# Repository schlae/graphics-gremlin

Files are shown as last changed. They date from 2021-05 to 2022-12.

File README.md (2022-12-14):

# The Graphics Gremlin - a Retro ISA Video Card

The Graphics Gremlin is an FPGA-based ISA video card specifically designed to emulate certain old video standards. This initial release emulates the original IBM PC monochrome graphics adapter (MDA) as well as the original IBM color graphics adapter (CGA). Since the logic is defined by the bitstream loaded into the FPGA, new emulations may be available in the future to support other video standards.

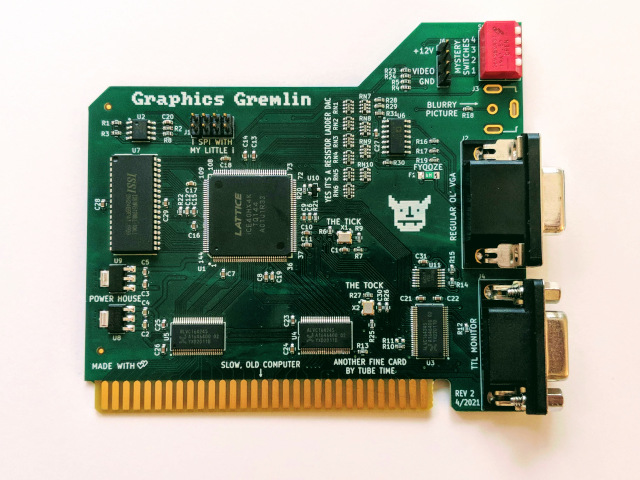
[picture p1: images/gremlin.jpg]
Graphics Gremlin PCB photo


But why emulate an old video card when they are still fairly easy to find online? Cards aren't hard to find, but monitors that can sync to the unusual frequencies used by MDA (18KHz) and CGA (15KHz) are much harder to find, and these frequencies are rarely supported by modern LCD monitors or video capture hardware.

For both MDA and CGA, the Graphics Gremlin has a VGA port that can deliver video running at standard (31KHz) frequencies that are well supported by LCD monitors, VGA-to-HDMI converters, and USB capture devices.

Here are the design files. The BOM includes Mouser Electronics parts numbers for everything except for the 0.1" headers which are typically cut to length anyway.

[Schematic](https://github.com/schlae/graphics-gremlin/blob/main/isavideo.pdf)

[Bill of Materials](https://github.com/schlae/graphics-gremlin/blob/main/isavideo.csv)

[Fab Files](https://github.com/schlae/graphics-gremlin/blob/main/fab/isavideo_rev2.zip)

## Fabrication and Assembly Notes

The circuit board is a 2-layer board, 4.19 x 3.74 inches (106 x 95mm). No special edge connector bevel is required, but you may want to specify at least ENIG plating. If you are rich then you could spend the extra money and get hard gold plated edge fingers. Order the boards with a fancy soldermask color so you can show off, or stick with a plain green to blend in.

You probably shouldn't attempt this project if you've never soldered surface mount components before. It'll lead to a lot of frustration and potentially damaged boards and parts.

There are two main methods you can use to assemble the board: reflow and hand soldering. Using the reflow method means that you'll need to order the solder stencil for the top side (there are no parts on the bottom of the board), and be sure to have fresh solder paste and some sort of vacuum pick-and-place tool. This method can be very quick but does require some skill and practice. 

Hand soldering is good when you only want to assemble a single board. This board has no BGA or leadless components which makes hand soldering possible. Some components have a very fine lead pitch (0.5mm) so only attempt this if you are comfortable with your soldering skills.

No matter which method you use, I recommend inspecting every solder joint very carefully under a microscope to make sure there are no solder bridges. If there are, clean them out with some solder braid.

Be careful not to mix up the two voltage regulators: they provide *different* voltages!

R11 should not be stuffed. By default this means that the 14.318MHz clock is generated on board. If you *move* R25 to R11, then the 14.318MHz clock comes from the ISA bus. The motherboard's 14.318MHz oscillator isn't always accurate enough for CGA color composite video.

Header J6 is optional. If you want to install it, remove pin 2 for keying.

Before plugging the card into a PC, it is wise to use a multimeter to verify that there are no short circuits between the +5V line (ISA bus pin B3) and ground or between the +12V line (ISA bus pin B9) and ground.

The card bracket may be fabricated from a plain, blank bracket such as a Keystone Electronics 9200. The dimensions are included in the KiCad file on the Dwgs.User layer. The best way to make holes in the bracket is by using a hand-operated sheet metal punch. A chassis nibbler is useful for making the DE-9 openings and the opening for the DIP switch bank.

You can also try 3D printing the bracket using the file below. There is a small line printed near the top which marks where you have to bend the bracket after you finish printing it. Use a hair dryer or a heat gun (on low) to soften it, and then bend it over a straightedge or ruler. For a slightly better finish on the outside of the bracket, flip it over in your slicer software so that the outside surface faces the bed of the printer.

[ISA bracket STL file](https://github.com/schlae/graphics-gremlin/blob/main/isabracket.stl)

## The FPGA
[A separate document discusses the Verilog code.](https://github.com/schlae/graphics-gremlin/blob/main/verilog/README.md)

Programming the FPGA is fairly easy and can be done with an FTDI FT2232H Mini Module [datasheet here](https://www.ftdichip.com/Support/Documents/DataSheets/Modules/DS_FT2232H_Mini_Module.pdf).

Wiring for the FT2232H mini module is as follows:

| Point 1 | Point 2 | Description |
| --- | --- | --- |
| CN2 pin 1  | CN2 pin 11 | V3V3 to VIO strap |
| CN3 pin 1  | CN3 pin 3 | VBUS to VCC strap |
| CN2 pin 3  | CN3 pin 12 | V3V3 to VIO strap (2) |
| CN2 pin 14  | SPI cable pin 1 | CS |
| CN2 pin 16  | SPI cable pin 2 | CDONE |
| CN2 pin 7 | SPI cable pin 3 | SCK (serial clock) |
| CN2 pin 15  | SPI cable pin 4 | CRESET |
| CN2 pin 9 | SPI cable pin 5 | CIPO (controller in, peripheral out) |
| CN2 pin 2 | SPI cable pin 6 | GND |
| CN2 pin 10  | SPI cable pin 7 | COPI (controller out, peripheral in) |
| n/a | SPI cable pin 8 | not used |

To program the FPGA, power needs to be applied. The simplest way to do this is to drop it in a nearby PC and turn it on. With the cable plugged in to a USB port, you can use the [Project IceStorm](http://www.clifford.at/icestorm/) tool "iceprog" to program the SPI flash memory.

`iceprog -p isavideo.binm`

Once the SPI flash has been programmed, iceprog toggles the reset line so that the FPGA loads the new bitstream. At this point it will be active on the ISA bus, but the PC's BIOS doesn't know about it. Reboot the computer and it should find it.

Note that leaving the programming cable plugged in can sometimes cause issues with the FPGA being held in reset when the PC powers up. In that case, simply unplug the cable and reboot the PC.

### Windows Instructions
Thanks to [midicdj1000](https://github.com/midicdj1000), here are some instructions for programming the FPGA using Windows.

1. Download and extract the Windows build of the [OSS CAD Suite](https://github.com/YosysHQ/oss-cad-suite-build/releases).
2. Connect the FT2232H mini module according to the directions in the previous section.
3. Install the [FTDI driver](https://ftdichip.com/drivers/).
4. Change the driver to libusbK using these [instructions](https://learn.adafruit.com/adafruit-ft232h-breakout/windows-setup).
5. From the command line in the Bin folder of the OSS-CAD-Suite folder, run `iceprog -p isavideo.binm`. (Be sure to include the appropriate path to the isavideo.binm file, or simply copy the file into the Bin folder.)

## The Red Switch Bank

The red switch bank on the top right of the card controls two things: the bitstream selected by the FPGA when it powers up and specific settings for the selected bitstream.

The bitstream is selected using switches 3 and 4:

| 3 | 4 | Description  | Default |
| --- | --- | --- | --- |
| open | open | Bitstream 0  | MDA (VGA compatible signal) |
| open | closed | Bitstream 1  | MDA (MDA monitors only) |
| closed | open | Bitstream 2  | CGA (both VGA and CGA compatible signals) |
| closed | closed | Bitstream 3  | Not used |

For example, if you want to use MDA with a VGA monitor, set switches 3 and 4
to the open (up) position. (CGA has support for both VGA and CGA monitors built in since it implements a line doubler.)

The remaining two switches have a function that is bitstream-dependent.

| Switch | MDA (VGA comp.) | MDA | CGA |
| --- | --- | --- | --- |
| 1 | Not used | Not used | closed=composite mode. open=VGA mode |
| 2 | Not used | Not used | closed=thin font. open=normal font |

## Connectors

The Graphics Gremlin provides both a 9-pin RGBI connector and a 15-pin VGA connector. The 9-pin connector is designed for use with digital monitors such as the IBM 5151, 5153, or a variety of older multisync monitors.

The RCA jack is used for CGA composite video when that bitstream is selected (see the previous section). Note that the signal for the RCA jack is also used as the green channel for the VGA connector so they cannot both be used at the same time.

Connector J6 is for compatibility with IBM CGA cards which provide the composite signal for RF modulators. This connector is really only useful if you want to use the card with an IBM 5155 Portable PC (the internal monitor has a cable that plugs into this connector).

## Troubleshooting

This is a complex card with many fine-pitch components, so most likely any issues you run into will be caused by a solder bridge or broken connection. Go back and check each solder joint using a microscope. Make sure you didn't install any chips or the clock oscillators the wrong way around.

A few things to confirm for basic operation include:

1. Are the 3.3V and 1.2V regulators putting out those voltages?
2. Are the two clock oscillators generating 10MHz and 14.318MHz?
3. Can the SPI flash get programmed by the FTDI board *and verified?*

Unlike the namesake video cards of old, the FPGA comes up with the internal card registers fully programmed and the card should generate video even if the ISA bus interface isn't working at all. A simple check involves configuring the switch bank for CGA and confirming that it produces a video signal. You can even flip to composite mode to make sure that works as well.

Checking these first can help you narrow down the source of the problem.

To confirm proper operation on the ISA bus, it's helpful to set up a PC with a VGA card (or CGA card) and the Graphics Gremlin configured for MDA. These can coexist on the same PC.

Boot up the PC and run the DOS DEBUG program. Then see if you can access the CRTC registers. Unlike the original MDA card, these can be read back. Note: if you use the VGA compatible MDA mode, then these registers cannot be written to.

```
o 3b4 0
i 3b5
```

This should return a number that is not 0 or FF. (The exact number depends on which MDA bitstream you are using).

If that works, then check to see if you can read and write the MDA video memory area:

`e b000:0000 55 aa 55 aa`...

and to check what you just wrote

`d b000:0000`

This will exercise the connections to the SRAM.

Other strange things that can happen:
* If the PC just beeps out an error code during startup, check for motherboard jumpers or switches that have to be set. You might also try a dual video card setup with a VGA card.
* If the PC never boots at all, it could be that the IO\_READY pin (A10) on the ISA bus is stuck low. Also check for any short circuits on the address, data, or control lines.
* If the PC power supply refuses to start or if there is smoke, then you probably have a short circuit on the +5V or +12V line on the card. Check for things like solder paste smeared underneath capacitors or traces shorted to the ground plane.

In general, use a logical process of elimination to find where the fault (or faults!) lurks.

## Emulation Accuracy

The logic for both the MDA and CGA cards is as close as I could get it to match the schematics available in the technical reference manuals, with two exceptions. The VRAM interface is specific to the 8-bit SRAM chip that I am using instead of the 16-bit SRAM on the original MDA or the 16-bit DRAM used on the CGA, so it had to be quite different from the originals. As a result, the sequencer state machine had to be designed from scratch. There are some other minor differences mostly to support the nonstandard VGA-compatible signal outputs.

Accuracy is a work in progress. Certain demos, like 8088MPH, that require cycle-accurate operation on a 4.77MHz PC, don't work 100% correctly. The causes of this aren't yet fully understood.

## Future Plans

Although the card supports just MDA and CGA, I'd like to support other video standards in the future. EGA and even VGA would be nice, but there are two huge challenges associated with that: they use custom gate array chips and they also use a 32-bit memory bus. This means I would need to quadruple the pixel clock to produce four 8-bit fetches from the SRAM. Due to this bus bandwidth limitation, Super VGAs are totally off the table.

Other people have requested support for Hercules, Tandy, and PCjr graphics, which I might get around to implementing someday.

There are also some neat non-graphics uses for the card. With some clever programming, the card could be turned into a memory card to extend the RAM in some of the older IBM PC and XT machines (XMS RAM). It could also emulate an expanded memory card for machines that can't run EMM386. BIOS extension ROMs stored in the NOR flash chip could also be mapped to ROM areas in the PC memory map, which might also be useful.

The card could act as a fancy POST card, perhaps even with a mini bus analyzer built in (using a connected VGA monitor).

It's even theoretically possible to implement a sound card using the composite video jack (and 7-bit resistor DAC) as the sound output.

## License
This work is licensed under a Creative Commons Attribution-ShareAlike 4.0
International License. See [https://creativecommons.org/licenses/by-sa/4.0/](https://creativecommons.org/licenses/by-sa/4.0/).

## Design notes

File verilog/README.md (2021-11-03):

# The Graphics Gremlin - FPGA code

(Click here for the [main README](https://github.com/schlae/graphics-gremlin/blob/main/README.md))

The FPGA code is divided into two major sets of files, those for CGA graphics and those for MDA graphics. At some point I'll tidy up and make a nice organized directory tree, but for now they're all in the same place.

* mda\_top.v: The top level file instantiating the MDA graphics logic
* mda70\_top.v: An alternative top level file for VGA compatible MDA graphics
* mda.v: Implements MDA ISA interface, IO registers and instantiates the CRTC, SRAM interface, sequencer, and pixel engine
* crtc6845.v: This is my mostly-accurate recreation of the old Motorola 6845 CRT controller chip. It generates all the sync timings as well as the character and row addresses. There are probably slight differences between it and the real thing.
* mda\_sequencer.v: Controls timing across the entire card, deciding when to fetch SRAM data, look up character bits from the character ROM, and allow ISA bus access to the SRAM
* mda\_vram.v: Implements the state machine to arbitrate ISA bus and pixel engine access to the video ram (external SRAM)
* mda\_pixel.v: This is the pixel engine. It takes data coming from the SRAM, looks up the pixels in the character ROM, and shifts the data out one pixel at a time. 
* mda\_attrib.v: The attribute generator applies video attributes to the raw pixel data, including brightness, underline, inverse video, blinking. It also applies the blinking cursor.
* mda\_vgaport.v: This module turns the digital MDA video signals into numbers to drive the resistor ladder DAC connected to the VGA port. If you (gasp) dislike amber monochrome monitors, then you can hack this code to make it green or white.

CGA graphics logic is similar to MDA and shares the same crtc6845.v logic, but the cards are different enough that I couldn't share more.
* cga\_top.v: Instantiates top level CGA logic.
* cga.v: Implements the ISA bus interface, CGA control registers, wait state generator, and most of the other CGA modules
* cga\_sequencer.v: Generates most of the timing signals used on the card, including memory fetches and pixel engine timing.
* cga\_vram.v: Implements a very basic address MUX for the SRAM interface. This actually causes too much CGA snow, and should be improved using the MDA VRAM interface as a model.
* cga\_pixel.v: The CGA pixel engine takes data from the SRAM, does a character lookup (text mode only), and shifts the data out 1 or 2 bits at a time, depending on the video mode.
* cga\_attrib.v: The attribute generator applies video attributes to the raw pixels data, including color, brightness, and blinking.
* cga\_composite.v: Contains the flip flops used to generate NTSC composite color as well as new sync pulses. The output is a 7-bit signal passed off to the green DAC channel for the RCA jack on the card.
* cga\_scandoubler.v: A very basic scan doubler to convert 15.7KHz CGA video to 31.4KHz VGA video. To save memory, this is done using 4-bit digital RGBI signals.
* cga\_vgaport.v: This module takes RGBI digital video from the scan doubler and turns it into numbers that drive the resistor ladder DAC connected to the VGA port. It produces CGA brown instead of dark yellow.

Other miscellaneous files include:
* cga.hex and mda.hex: character ROM
* gremlin.pcf: The pin constraints file that determines what signals are tied to what pins on the FPGA
* isavideo\_t.v: A sloppy test bench that I used to validate and troubleshoot the rest of the logic.
* is61c5128\_t.v: A behavorial Verilog model of the SRAM chip.
* is61\_tester.v: A test bench I used to verify the SRAM chip behavioral model.

## Building

To build the project, you will need to install the tools from [Project IceStorm](http://www.clifford.at/icestorm/) (full instructions are available at that link). The Graphics Gremlin uses NextPNR, so make sure you install that.

Alternatively, you can install the [OSS Cad Suite](https://github.com/YosysHQ/oss-cad-suite-build) which is prebuilt and runs on a variety of platforms.

Once the tools are installed, just navigate to the Graphics Gremlin Verilog directory and run
```
mkdir build
make
```
If you have the FTDI programming cable hooked up to the card, you can also type `make prog`. As a convenience, `make reset` will not program the FPGA but will toggle its reset line which is useful if you change the red switch bank and don't want to cycle power on the host PC.

If the `make prog` command can't find the FTDI programming cable, make sure you have the udev rules set up.

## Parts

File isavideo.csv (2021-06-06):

Item | Qty | Reference(s) | Value | Mouser
1 | 23 | C1, C7, C8, C9, C10, C11, C13, C14, C15, C16, C17, C20, C21, C22, C23, C24, C25, C26, C27, C28, C29, C30, C31 | 1u | 810-CGA3E1X7R1C105AC
2 | 8 | C2, C3, C4, C5, C6, C12, C18, C19 | 4.7u | 187-CL10A475KP8NNNC
3 | 1 | F1 | 1A | 530-0ZCJ0050FF2G
4 | 1 | J1 | PROG
5 | 1 | J2 | DE15 | 156-3315-E
6 | 1 | J3 | NTSC | 161-0360-E
7 | 1 | J4 | DE9 | 152-3409
8 | 1 | J6 | RFMOD
9 | 13 | R1, R2, R3, R4, R5, R8, R9, R14, R15, R20, R23, R24, R27 | 10K | 603-RC0603FR-0710KL
10 | 5 | R6, R7, R10, R25, R26 | 10 | 603-RC0603FR-0710RL
11 | 1 | R11 | DNI | DNI
12 | 3 | R12, R21, R22 | 100 | 603-RC0603FR-07100RL
13 | 1 | R13 | 1K | 603-RC0603FR-071KL
14 | 5 | R16, R17, R18, R19, R31 | 75 | 603-RC0603FR-0775RL
15 | 3 | R28, R29, R30 | 237 | 603-RC0603FR-07237RL
16 | 6 | RN1, RN2, RN3, RN4, RN5, RN6 | 604 | 652-CAY16-6040F4LF
17 | 4 | RN7, RN8, RN9, RN10 | 300 | 652-CAY16-3000F4LF
18 | 1 | SW1 | SW_DIP_x04 | 706-76PSB04ST
19 | 1 | U1 | ICE40HX4K-TQ144 | 842-ICE40HX4K-TQ144
20 | 1 | U2 | SST26VF080A-104I/SN | 579-26VF080A-104I/SN
21 | 3 | U3, U4, U5 | 74ALVC164245 | 771-74ALVC164245
22 | 1 | U6 | ADA4891-3 | 584-ADA4891-3ARZ
23 | 1 | U7 | IS61WV5128BLL-10KLI | 870-61WV5128B10KLI
24 | 1 | U8 | AP2114HA-3.3 | 621-AP2114HA-3.3TRG1
25 | 1 | U9 | AP2114HA-1.2 | 621-AP2114HA-1.2TRG1
26 | 1 | U10 | APX803S00-29SA-7 | 621-APX803S00-29SA-7
27 | 1 | U11 | 74HCT125 | 771-74HCT125PW-T
28 | 1 | X1 | 10MHz | 520-ECS-2333-100-BNT
29 | 1 | X2 | 14.318MHz | 815-ASE-14.318MLCT

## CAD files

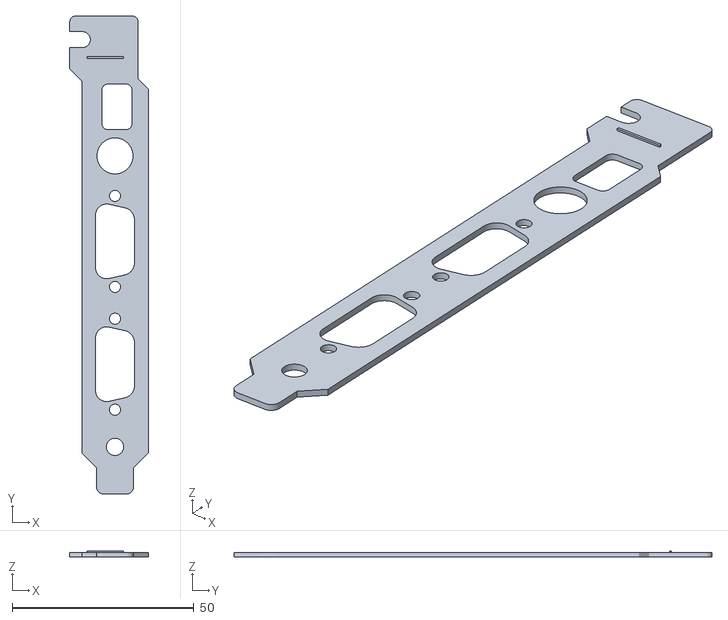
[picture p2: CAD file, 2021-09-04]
isabracket.stl
21.6 x 131.4 x 1.67

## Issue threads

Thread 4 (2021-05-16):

Question about the specified board size

ecm-pushbx, 2021-05-16:
I don't really go here but I found the following part of the readme file curious:

> The circuit board is a 2-layer board, 4.19 x 4.2 inches (106 x 95mm).

1. The shorter and longer sides seem to be swapped between the inches and millimetres specifications.
2. I don't see how the values are accurate matches. Perhaps the "4.2 inches" should be "4.02 inches"? That still wouldn't match exactly though.

schlae, 2021-05-16:
The height should be 3.74in, or 95mm. I've corrected it in the board file and the readme.

Closed 2021-05-16.

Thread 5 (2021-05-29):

MDA 70Hz RAM issues

schlae, 2021-05-29:
MDA (70Hz VGA compatible) on some boards has issues with the attribute byte getting corrupted by the previously-read character byte. This shows up as spurious underlines, inverse video, etc on the screen. Likely this is a marginal timing issue as it works fine on some boards but not others.

spark2k06, 2021-10-30:
I have investigated and discovered something about this issue, and that is that the final timing resulting from the build plays an important role. The most curious thing is that this final timing can be manipulated by inserting or extracting modules not required by the project.

So, for example, a build only with the modules required by the project:

`yosys -p 'synth_ice40 -top mda70_top -json build/mda70_top.json' mda70_top.v mda.v crtc6845.v mda_vgaport.v mda_vram.v mda_attrib.v mda_sequencer.v mda_pixel.v -E mda70_top.d
`

`Total path delay: 12.21 ns (81.89 MHz)`

This timing seems that it would not be compatible with any board, causing artifacts.

Ahora, con la build utilizada por el Makefile, basada en los últimos cambios que afectarían sólo al proyecto de CGA:

`yosys -p 'synth_ice40 -top mda70_top -json build/mda70_top.json' mda70_top.v mda_top.v mda.v crtc6845.v mda_vgaport.v mda_vram.v mda_attrib.v mda_sequencer.v mda_pixel.v cga_top.v cga.v cga_vgaport.v cga_sequencer.v cga_pixel.v cga_attrib.v cga_vram.v cga_composite.v cga_scandoubler.v -E mda70_top.d `

`Total path delay: 12.66 ns (78.98 MHz)`

This timing is what causes underlines to occur on some boards, and only show some artifacts. However, if we repeat the command but with the old CGA project files, we get the following result:

`Total path delay: 13.12 ns (76.24 MHz)`

Now yes, this timing could be friendlier with all boards, at least it is with mine:

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

And the most curious thing is that adding repeated modules does not always cause a lower timing, sometimes the opposite happens ... in the tests I have done, I have obtained different timings:

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

In conclusion, timings higher than 80 Mhz could affect any board, and the main symptom is artifacts, which would increase as the frequency is higher. On the other hand, there is a point at which, the timings could be stable on any board, 77Mhz and lower.

schlae, 2021-10-30:
Thanks for going through this, it's a good clue about the root cause of the problem, which is probably the bus timing of the SRAM chip. The fetching of the character and attribute byte are in successive cycles, but perhaps there's not enough time allowed for the address to stabilize before the byte gets latched.

spark2k06, 2021-11-06:
With the latest version of yosys (0.11+1) this issue is also corrected, without the need to make changes to the code.

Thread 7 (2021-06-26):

Can I replace with ICE40HX1K-TQ144?

yeokm1, 2021-06-26:
Hi

I'm intending to assemble your board however I realised ICE40HX4K-TQ144 is out of stock everywhere.

Will a ICE40HX1K-TQ144 work instead?

schlae, 2021-06-26:
No, the 1K has fewer I/O pins, and the Gremlin uses nearly every available I/O on the 4K. You'll just have to wait until they get back in stock.

Closed 2021-06-26.

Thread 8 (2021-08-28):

ICE40HX chips might have 5V tolerant I/O

kiwidrew, 2021-08-28:
If you're willing to live a little bit dangerously the second 74ALVC164245 (U5) may not be necessary because [it appears that the HX4K has 5V tolerant I/O pins](https://www.eevblog.com/forum/fpga/ice40-hx-a-5v-tolerant-fpga/) despite what the datasheet claims.

schlae, 2021-11-05:
I hesitate to design it this way--the FPGA won't last as long due to possible electromigration effects.

Closed 2021-11-05.

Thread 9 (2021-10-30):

MDA 70Hz out of sync with the first MSDOS EDIT

spark2k06, 2021-10-30:
I do not know if it is something that only happens to me, but below I show a video where this effect can be observed. First run of MSDos EDIT command, results in VGA out of sync, I go out and back in, and it always works fine now:

https://youtu.be/G0YuSTjFQO0

spark2k06, 2023-01-25:
It could be related to the CRTC registry values, discussed in the next issue:

https://github.com/schlae/graphics-gremlin/issues/15

Closed 2023-01-25.

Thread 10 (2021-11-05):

Latest yosys synthesis results in missing CGA characters

schlae, 2021-11-05:
Using the 3-Nov-2021 build of oss-cad-suite-build results in the CGA text generation code not synthesizing correctly. Instead of a full character, each cell just displays a single column.

avlixa, 2021-11-20:
Hi,
Try changing this in cga_pixel.v

    // This must be a mux. Using a shift register causes very weird
    // issues with the character ROM and Yosys turns it into a bunch
    // of flip-flops instead of a ROM.
    wire [2:0] charpix;
    assign charpix = hres_mode ? (clk_seq[3:1] + 3'd6) : (clk_seq[4:2] + 3'd7);

    always @ (*)
    begin
        if (video_enabled) begin
            // Hi-res vs low-res needs different adjustments
            //case (hres_mode ? (clk_seq[3:1] + 3'd6) : (clk_seq[4:2] + 3'd7))
            case (charpix)

It seems using the sentece directly in the case is generating a signal with more than 3 bits.  I tried it in @spark2k06 ZXUncore version and it works.

schlae, 2021-11-20:
Yes, this makes sense. The original design infers an adder and there's an ambiguity regarding the resulting bit width: looks like the newer versions of Yosys include the carry out which makes the mux 4 bits wide instead of 3. The result doesn't wrap correctly and triggers the default case for most of the clock sequence. I've pushed your recommended fix, thanks for looking at it!

Closed 2021-11-20.

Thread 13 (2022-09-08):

Unavailability of parts

0ddjob, 2022-09-08:
A few parts are currently unavailable from several suppliers with long lead-times from the manufacturer - is there a possibility of alternatives?

U1: iCE40HX4K-TQ144
U10: APX803S00-29SA-7

schlae, 2022-09-08:
U10: A large number of alternatives are available, this is a clone of a MAX803. be sure to check voltage levels and pinouts before substituting.
U1: No alternatives. We just have to wait until it gets back into stock :(

midicdj1000, 2022-12-15:
HI, Any alternatives for the RCA socket ?

Closed 2022-09-08.

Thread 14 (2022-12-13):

I am just looking for more information that is beginner friendly

midicdj1000, 2022-12-13:
HI, I have lots of experience assembling boards, but not so much programming fpga so when it gets to the part that says run iceprog to program and you then spend days following guides and compiling this and messing with linux only too find a windows version the next day  then the ftdi programmer needs to have it's driver forced because iceprog can't find it and it can't be on a certain sub port, you can imagine someone who does not have fpga experience can have one or two problems.

So after a lot of messing about I can talk to the ftdi, but it will not program the fpga so I need to check a lot of things.

This is how to change the driver
https://github.com/YosysHQ/icestorm/issues/141

and the windows build
https://github.com/YosysHQ/oss-cad-suite-build/releases

Once I have everything working I could document and perhaps it will help others.

midicdj1000, 2022-12-13:
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
This is how far I am and clearly have a big problem with the fpga not running or how I connected the programmer ?

midicdj1000, 2022-12-13:
Success.... I missed one of the connections for the ftdi power setup and it's programmed and is working.
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

midicdj1000, 2022-12-13:
This is how I did it.
Download and extract
https://github.com/YosysHQ/oss-cad-suite-build/releases

Connect the ftdi as per the instructions

install the ftdi driver
https://ftdichip.com/drivers/

Follow these instructions to change the driver to libusbK
https://learn.adafruit.com/adafruit-ft232h-breakout/windows-setup

copy isavideo.binm into the Bin folder of the OSS-CAD-Suite install

then you can run
iceprog -p isavideo.binm

I hope this helps windows users

Closed 2022-12-13.

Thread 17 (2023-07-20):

Memory errors in CheckIt, screen corruption in MDA mode

skiselev, 2023-07-20:
The FPGA byte code from November 20, 2021 (the latest) produces memory errors at certain memory addresses in both MDA and CGA modes.
It also results in memory/screen corruption in MDA mode. The location on the screen seem to correspond to these addresses (typically column 64).
The issue is reproducible in several cards built exactly according to the BoM.

Typical error locations:
* CGA: 0xB9000, 0xBA000
* MDA: 0xB0080, 0xB0400, 0xB0800, 0xB0880, 0xB0C80

Different cards might show errors only in some of these locations. Perhaps there is a timing violation that results in memory corruption in for these certain addresses

schlae, 2023-07-20:
Yes, it's a timing issue, I haven't yet been able to track it down.

skiselev, 2023-07-20:
Tried rebuilding with Yosys-0.31+1 (oss-cad-suite-linux-x64-20230719.tgz), and I am getting even more memory corruption.
Seems to be every location 0x20'th location
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

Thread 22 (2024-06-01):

Exact wiring when using UM-FT2232H instead of FTDI FT2232H Mini Module

explit7, 2024-06-01:
I want to use the ELV UM-FT2232H Kit because its much cheaper than the FTDI FT2232H Mini Module.
The wiring is a bit different than that, what you give for FTDI FT2232H Mini Module:
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

I found where to connect the AD0, AD1, AD2, AD4, AD6, AD7 and GND lines,
ELV UM-FT2232H         Graphics Gremlin SPI

- PIN9 (AD4)             ->    PIN1
- PIN11 (AD6)           ->    PIN2
- PIN5 (AD0)             ->    PIN3
- PIN12 (AD7)           ->    PIN4
- PIN7 (AD2)             ->    PIN5
- PIN4 GND)             ->    PIN6
- PIN6 (AD1)             ->    PIN7

but what i dont understand are the:
V3V3 to VIO strap
VBUS to VCC strap
V3V3 to VIO strap (2)

Maybe you can give a short explanation which PINs i need to use for this 3 connections?
Thanks
[https://github.com/mariusgreuel/um-ft2232h?tab=readme-ov-file](url)

Update: I could program graphics gremlin, without this 3 wires, but i don't know, if it can be dangerous for the FPGA

explit7, 2024-06-24:
I will close this issue, as it seems, that the Pins

- V3V3 to VIO strap
- VBUS to VCC strap
- V3V3 to VIO strap (2)

which are missing on ELV UM-FT2232H are not necessary to flash the cardd

Closed 2024-06-24.

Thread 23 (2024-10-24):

Centroid file

cstruter, 2024-10-24:
I just ordered this on pcbway, but you didnt supply a centroid file.
[https://www.pcbway.com/project/shareproject/The_Graphics_Gremlin_a_Retro_ISA_Video_Card_8294bddc.html](url)

cstruter, 2024-10-24:
[PickAndPlace_isavideo_2024-10-24.xlsx](https://github.com/user-attachments/files/17511319/PickAndPlace_isavideo_2024-10-24.xlsx)
Is this good enough?

schlae, 2024-10-24:
Fixed, the CSV coordinate file is now in the fab package, see 9954a99.

Closed 2024-10-24.

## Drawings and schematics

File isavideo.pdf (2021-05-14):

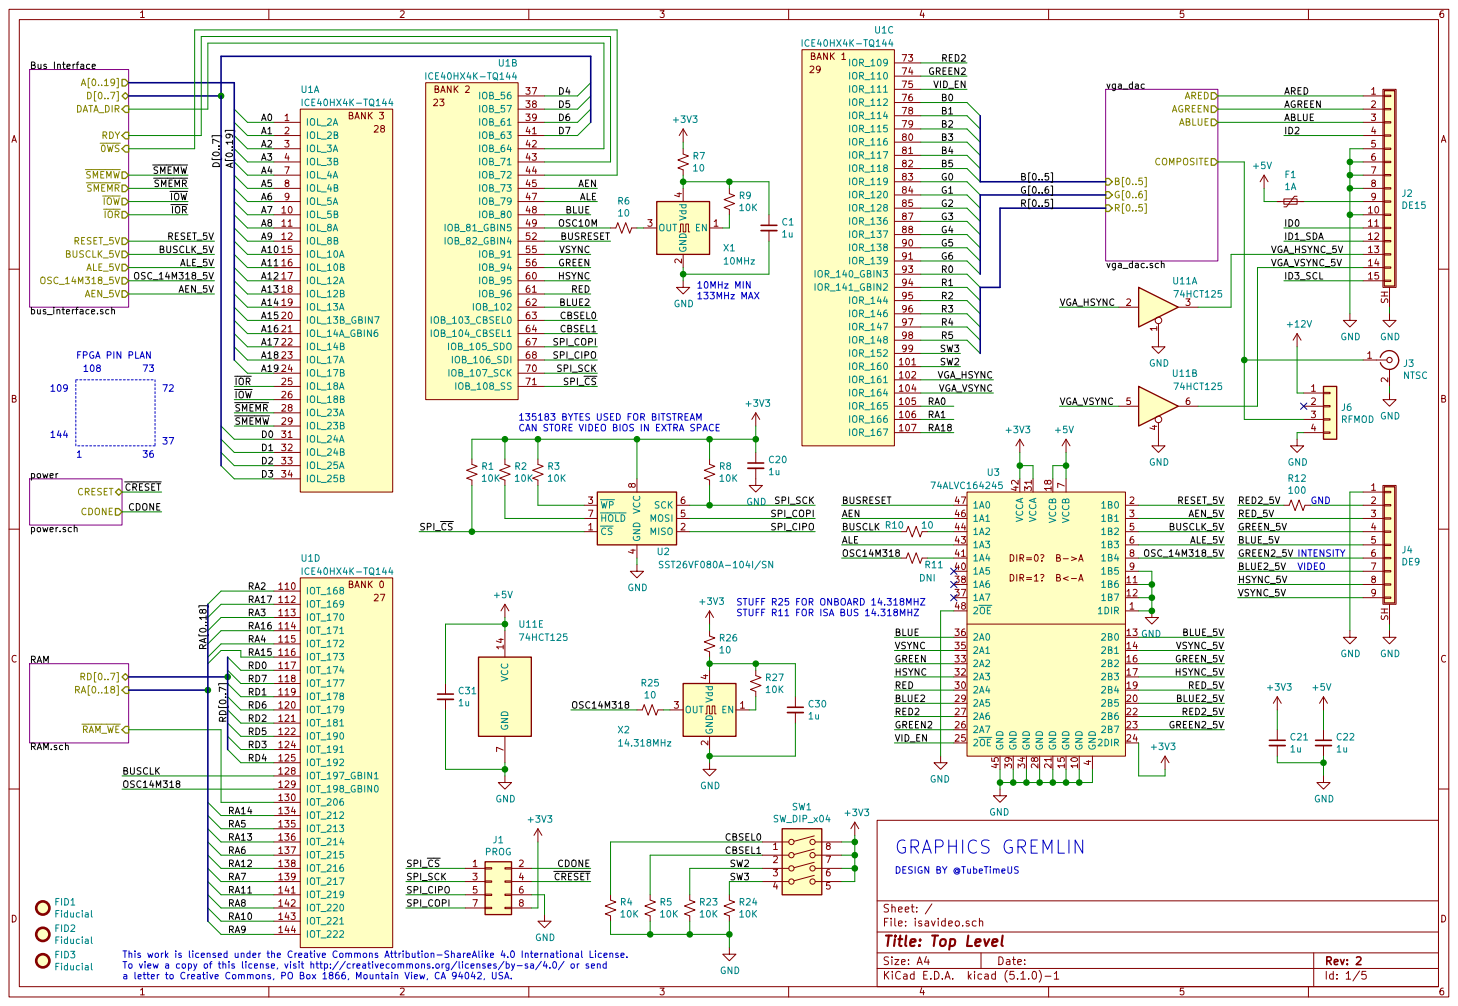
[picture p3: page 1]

AEN
ALE
BLUE
STUFF R25 FOR ONBOARD 14.318MHZ STUFF R11 FOR ISA BUS 14.318MHZ OSC10M

74HCT125 VCC 14 GND
135183 BYTES USED FOR BITSTREAM

4 MOSI 5 SCK 6 HOLD 7 VCC

IOT_198_GBIN0 129
IOT_206 130

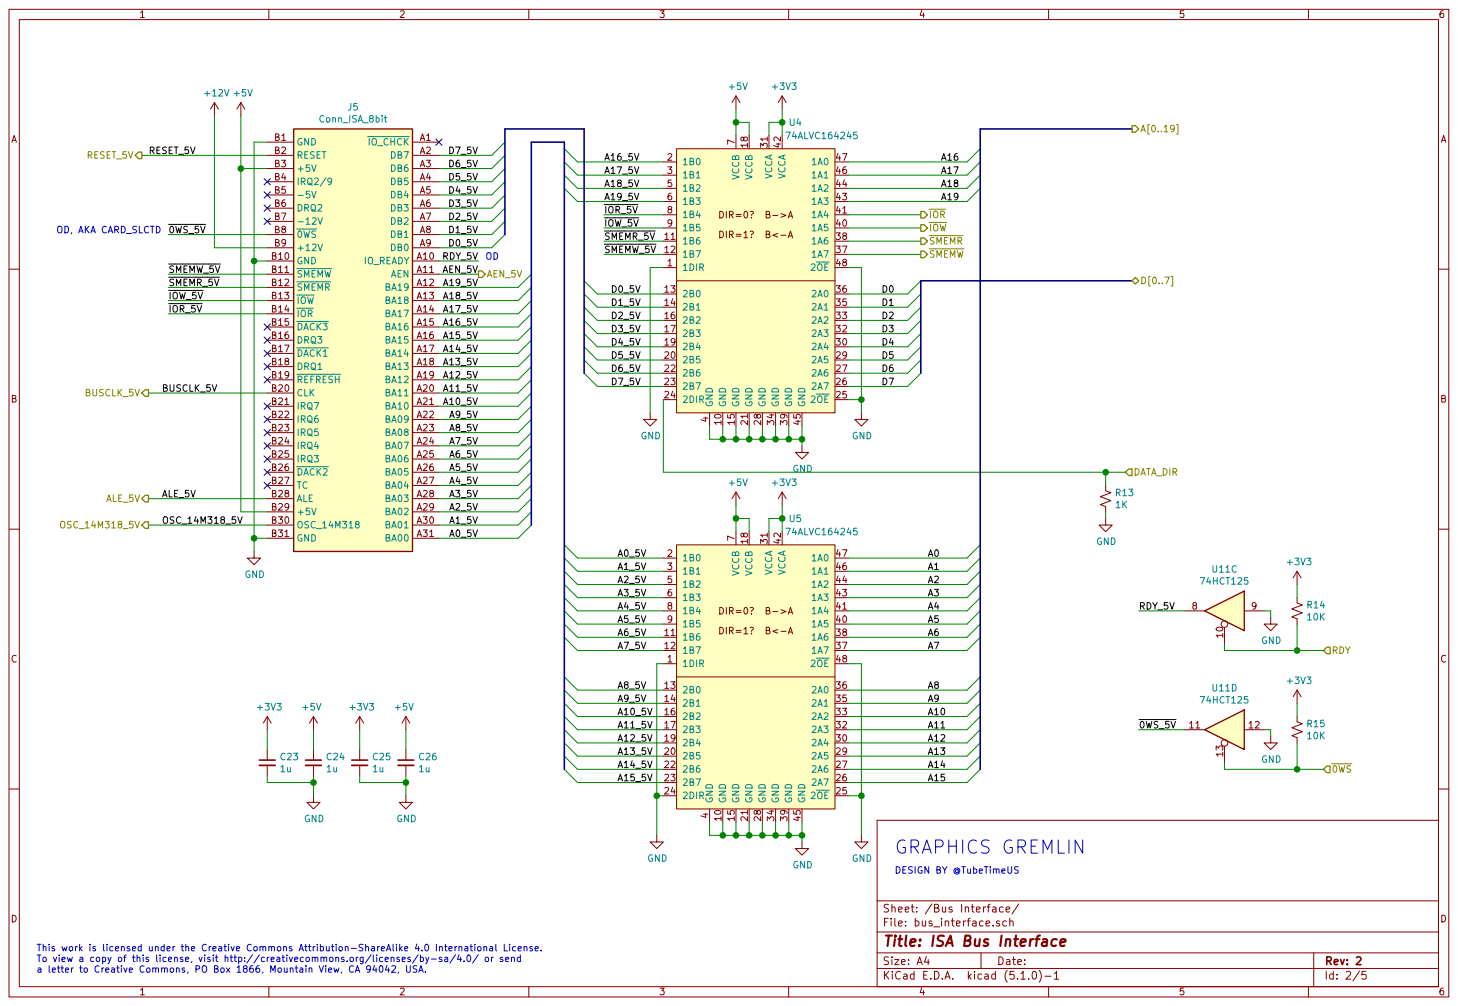
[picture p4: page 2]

File: bus_interface.sch Sheet: /Bus Interface/ GND

Id: 2/5 Title: ISA Bus Interface

This work is licensed under the Creative Commons Attribution-ShareAlike 4.0 International License. To view a copy of this license, visit http://creativecommons.org/licenses/by-sa/4.0/ or send

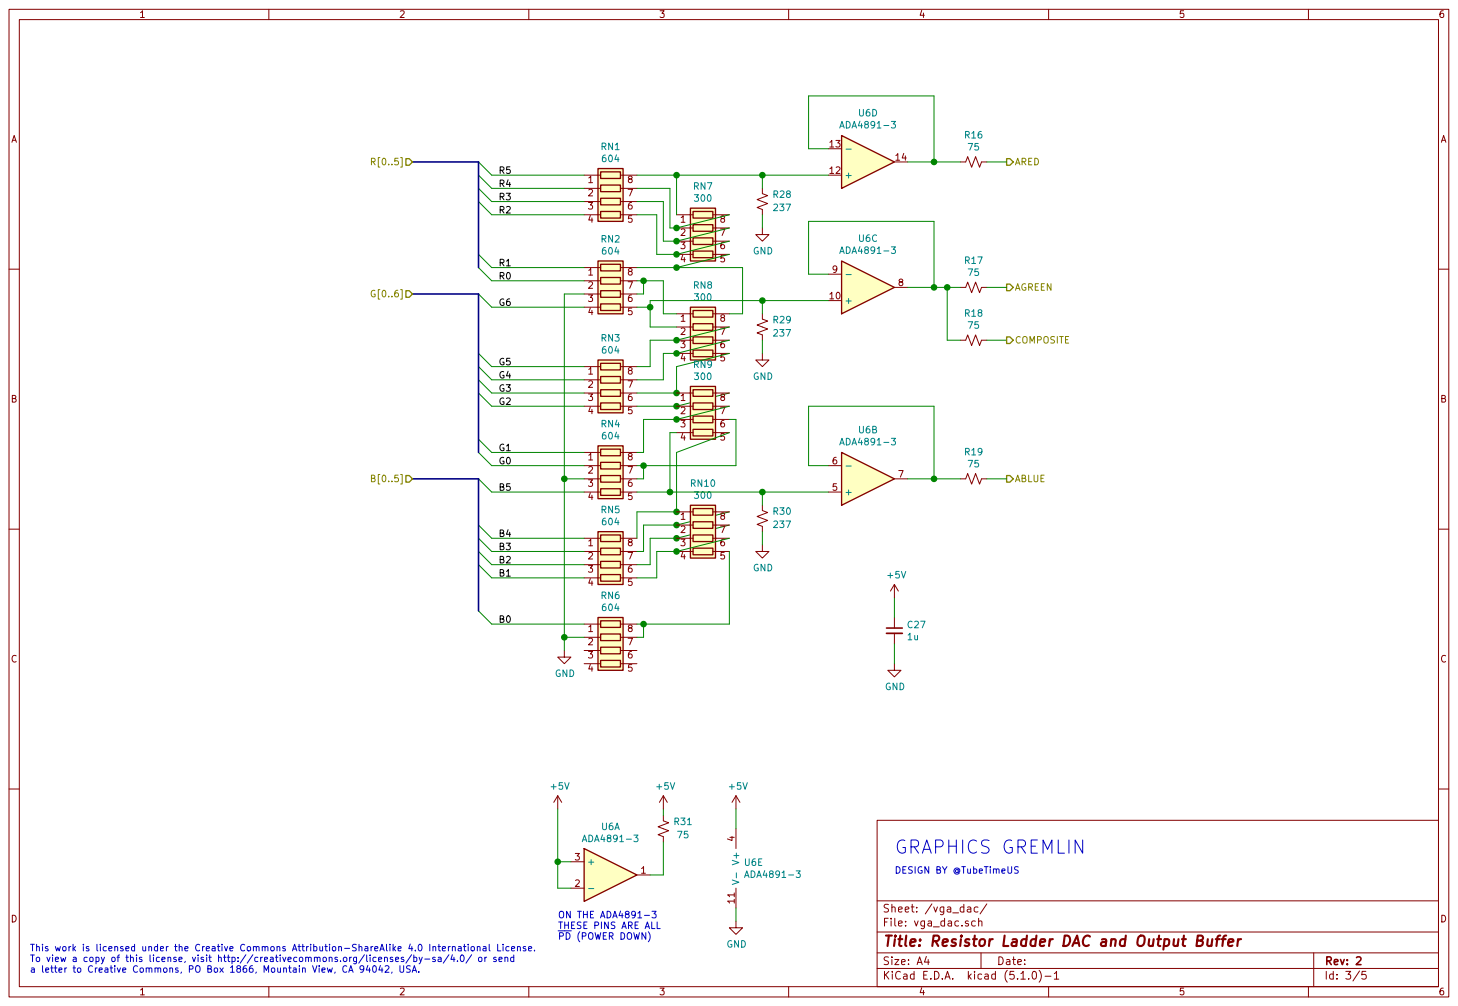
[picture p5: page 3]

75 +5V ON THE ADA4891-3 THESE PINS ARE ALL PD (POWER DOWN)

File: vga_dac.sch
Id: 3/5 Title: Resistor Ladder DAC and Output Buffer

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

a letter to Creative Commons, PO Box 1866, Mountain View, CA 94042, USA.

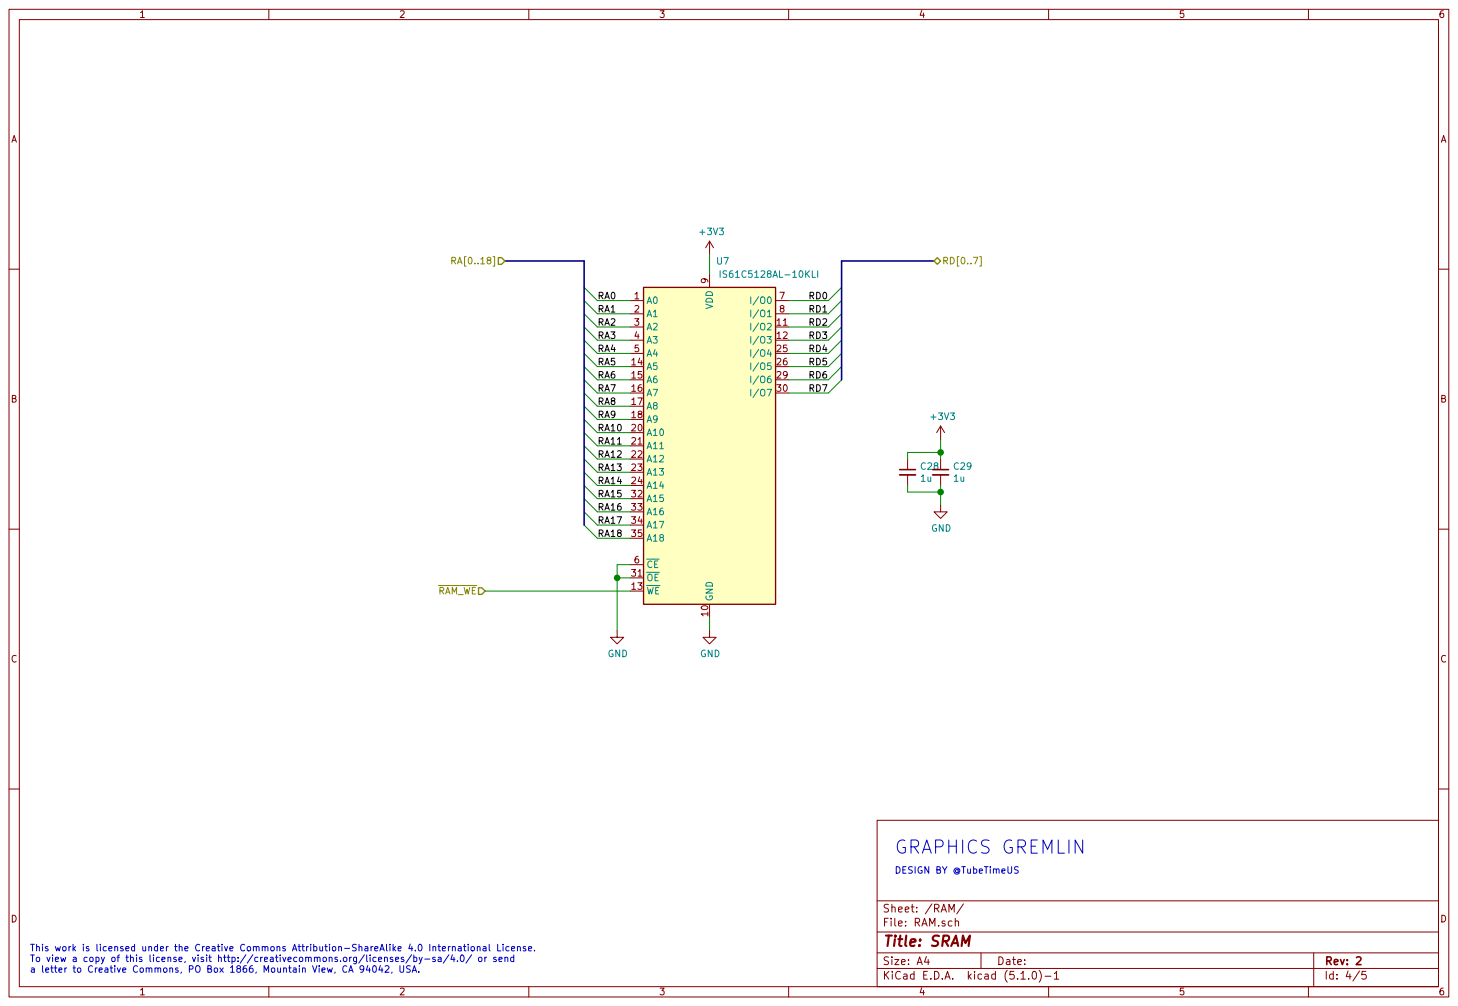
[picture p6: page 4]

File: RAM.sch Sheet: /RAM/
Id: 4/5 Title: SRAM

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

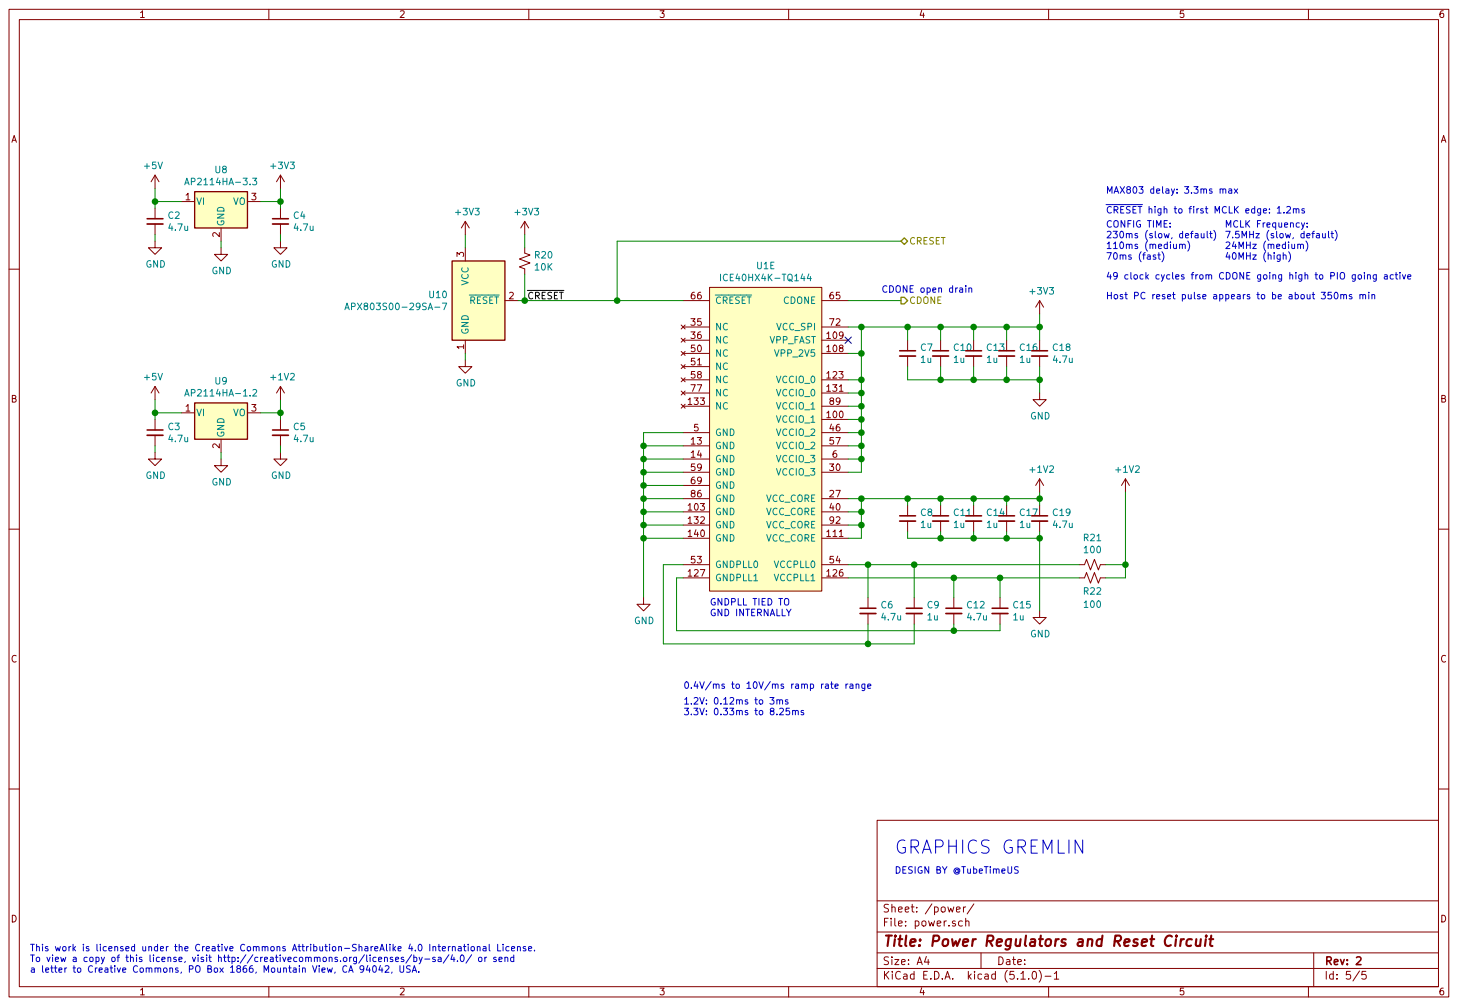
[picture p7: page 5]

CRESET high to first MCLK edge: 1.2ms

110ms (medium)
70ms (fast)
49 clock cycles from CDONE going high to PIO going active

0.4V/ms to 10V/ms ramp rate range

File: power.sch
Id: 5/5 Title: Power Regulators and Reset Circuit

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

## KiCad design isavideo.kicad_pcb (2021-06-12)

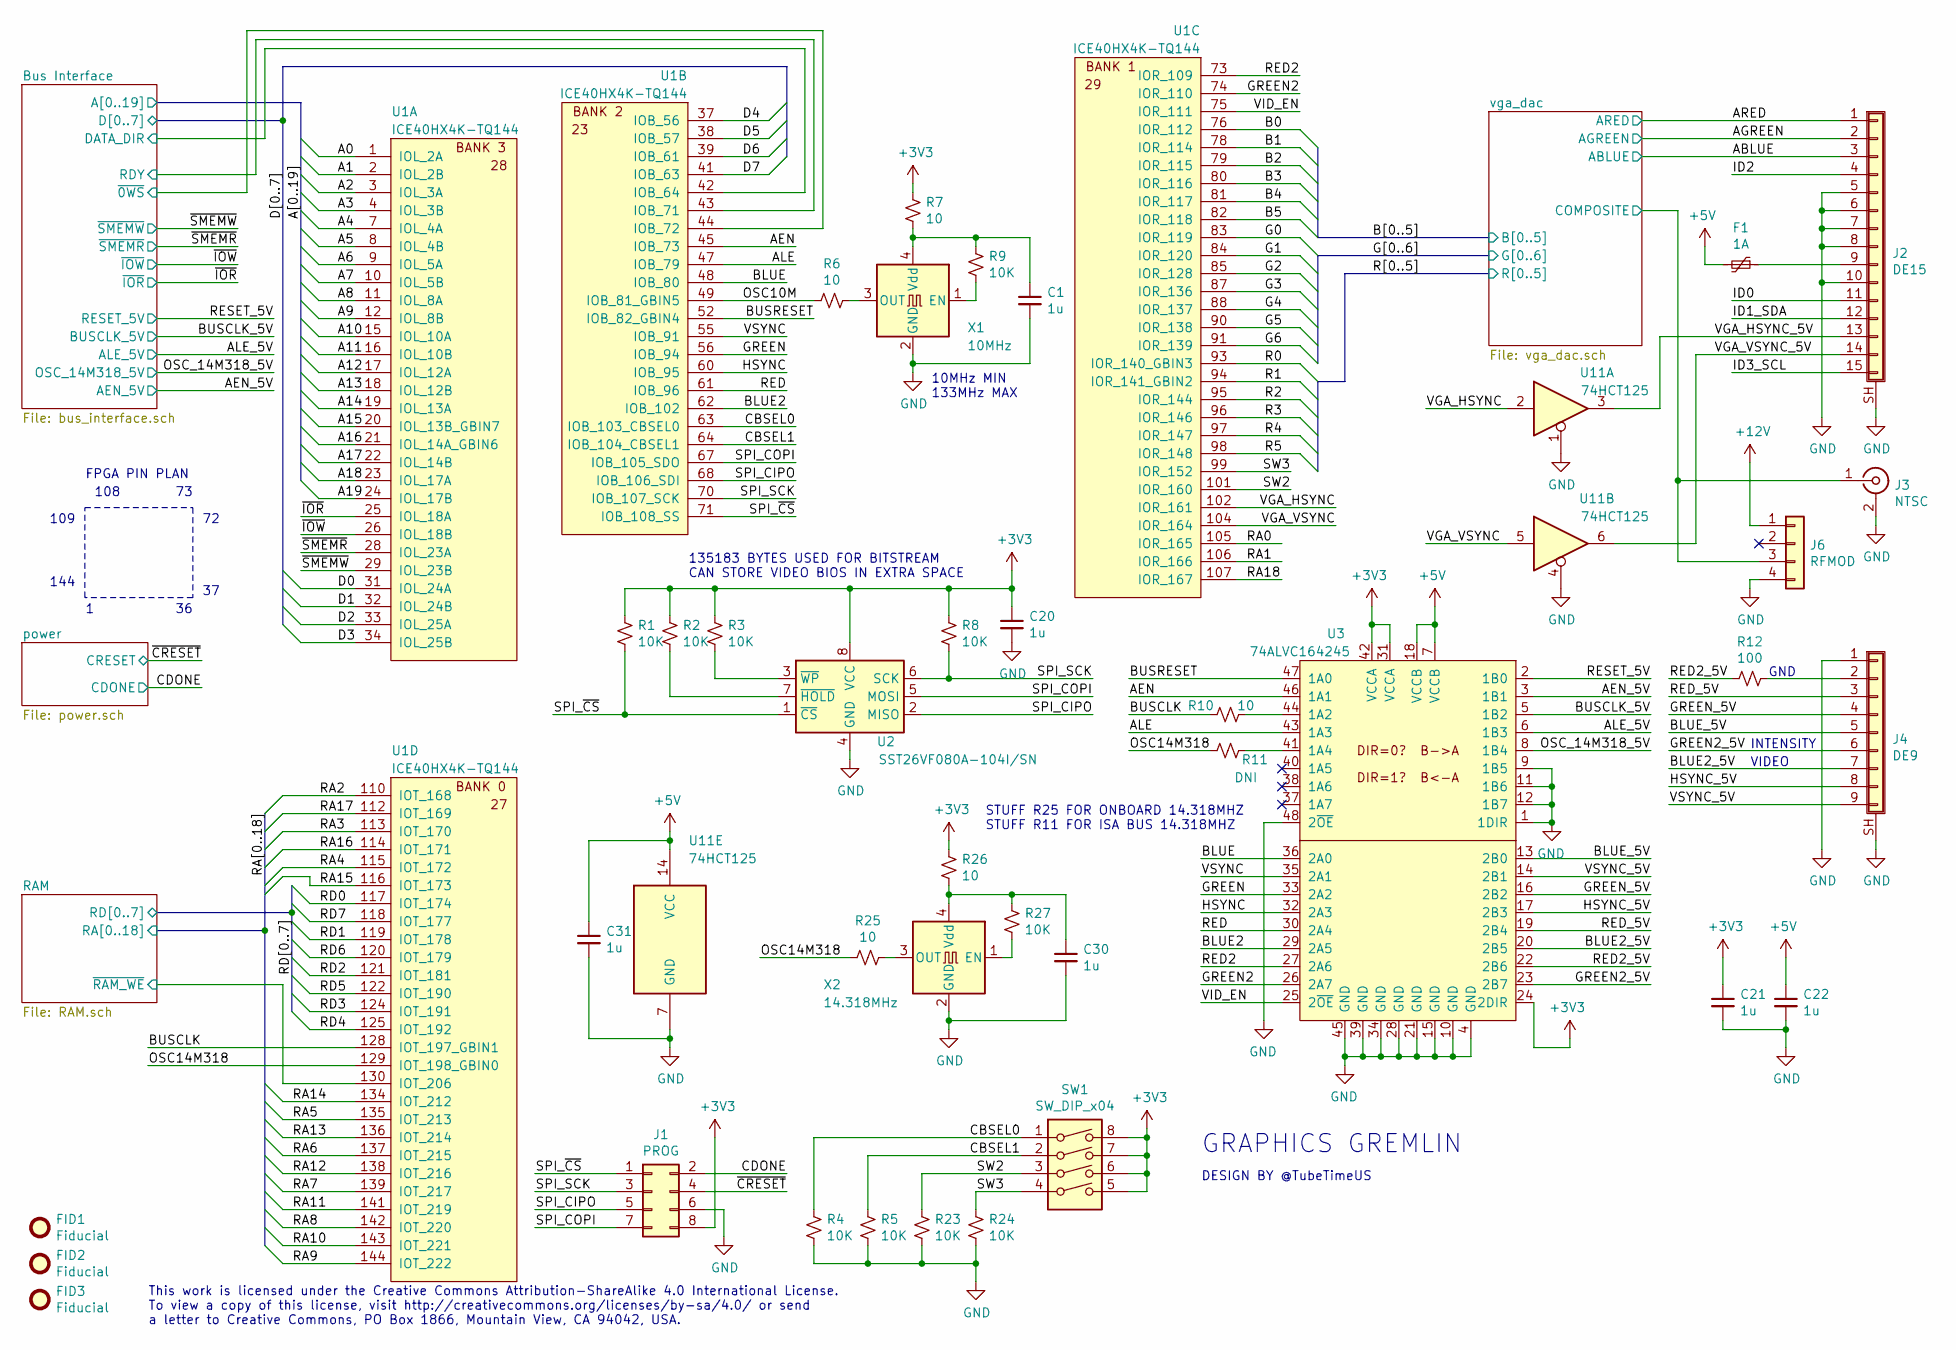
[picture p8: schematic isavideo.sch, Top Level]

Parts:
C1, C20, C21, C22, C30, C31: 1u; CAPC1608X100; Mouser 810-CGA3E1X7R1C105AC
F1: 1A; RESC3216X70; Mouser 530-0ZCJ0050FF2G
FID1, FID2, FID3: Fiducial; Fiducial_1mm_Dia_2mm_Outer
J1: PROG; Pin_Header_Straight_2x04_Pitch2.54mm
J2: DE15; DB15HDFC; Mouser 156-3315-E
J3: NTSC; KOBICONN_161-03X0-E; Mouser 161-0360-E
J4: DE9; DB9FC2; Mouser 152-3409
J6: RFMOD; Pin_Header_Straight_1x04_Pitch2.54mm
R1, R2, R3, R4, R5, R8, R9, R23, R24, R27: 10K; RESC1608X55; Mouser 603-RC0603FR-0710KL
R6, R7, R10, R25, R26: 10; RESC1608X55; Mouser 603-RC0603FR-0710RL
R11: DNI; RESC1608X55; Mouser DNI
R12: 100; RESC1608X55; Mouser 603-RC0603FR-07100RL
SW1: SW_DIP_x04; SW_DIP254P762X635-8; Mouser 706-76PSB04ST
U1: ICE40HX4K-TQ144; TSQFP50P2200X2200X160-144; Mouser 842-ICE40HX4K-TQ144
U2: SST26VF080A-104I/SN; SOP127P620X175-8; Mouser 579-26VF080A-104I/SN
U3: 74ALVC164245; TSSOP50P810X120-48; Mouser 771-74ALVC164245
U11: 74HCT125; TSOP65P640X110-14; Mouser 771-74HCT125PW-T
X1: 10MHz; XTAL320X250X120-4; Mouser 520-ECS-2333-100-BNT
X2: 14.318MHz; XTAL320X250X120-4; Mouser 815-ASE-14.318MLCT

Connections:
+3V3: C20.1, C21.1, J1.8, R1.1, R2.1, R3.1, R7.1, R8.1, R26.1, SW1.5, SW1.6, SW1.7, SW1.8, U2.8 (VCC), U3.24 (2DIR), U3.31 (VCCA), U3.42 (VCCA); also elsewhere on the board
+5V: C22.1, C31.1, F1.2, U3.7 (VCCB), U3.18 (VCCB), U11.14 (VCC); also elsewhere on the board
+12V: J6.1; also elsewhere on the board
/A0: U1.1 (IOL_2A); also elsewhere on the board
/A1: U1.2 (IOL_2B); also elsewhere on the board
/A2: U1.3 (IOL_3A); also elsewhere on the board
/A3: U1.4 (IOL_3B); also elsewhere on the board
/A4: U1.7 (IOL_4A); also elsewhere on the board
/A5: U1.8 (IOL_4B); also elsewhere on the board
/A6: U1.9 (IOL_5A); also elsewhere on the board
/A7: U1.10 (IOL_5B); also elsewhere on the board
/A8: U1.11 (IOL_8A); also elsewhere on the board
/A9: U1.12 (IOL_8B); also elsewhere on the board
/A10: U1.15 (IOL_10A); also elsewhere on the board
/A11: U1.16 (IOL_10B); also elsewhere on the board
/A12: U1.17 (IOL_12A); also elsewhere on the board
/A13: U1.18 (IOL_12B); also elsewhere on the board
/A14: U1.19 (IOL_13A); also elsewhere on the board
/A15: U1.20 (IOL_13B_GBIN7); also elsewhere on the board
/A16: U1.21 (IOL_14A_GBIN6); also elsewhere on the board
/A17: U1.22 (IOL_14B); also elsewhere on the board
/A18: U1.23 (IOL_17A); also elsewhere on the board
/A19: U1.24 (IOL_17B); also elsewhere on the board
/ABLUE: J2.3; also elsewhere on the board
/AEN: U1.45 (IOB_73), U3.46 (1A1)
/AEN_5V: U3.3 (1B1); also elsewhere on the board
/AGREEN: J2.2; also elsewhere on the board
/ALE: U1.47 (IOB_79), U3.43 (1A3)
/ALE_5V: U3.6 (1B3); also elsewhere on the board
/ARED: J2.1; also elsewhere on the board
/B0: U1.76 (IOR_112); also elsewhere on the board
/B1: U1.78 (IOR_114); also elsewhere on the board
/B2: U1.79 (IOR_115); also elsewhere on the board
/B3: U1.80 (IOR_116); also elsewhere on the board
/B4: U1.81 (IOR_117); also elsewhere on the board
/B5: U1.82 (IOR_118); also elsewhere on the board
/BLUE: U1.48 (IOB_80), U3.36 (2A0)
/BLUE2: U1.62 (IOB_102), U3.29 (2A5)
/BLUE2_5V: J4.7, U3.20 (2B5)
/BLUE_5V: J4.5, U3.13 (2B0)
/BUSCLK: R10.2, U1.128 (IOT_197_GBIN1)
/BUSCLK_5V: U3.5 (1B2); also elsewhere on the board
/BUSRESET: U1.52 (IOB_82_GBIN4), U3.47 (1A0)
/Bus Interface/DATA_DIR: U1.42 (IOB_64); also elsewhere on the board
/Bus Interface/RDY: U1.43 (IOB_71); also elsewhere on the board
/Bus Interface/~0WS: U1.44 (IOB_72); also elsewhere on the board
/CBSEL0: R4.1, SW1.1, U1.63 (IOB_103_CBSEL0)
/CBSEL1: R5.1, SW1.2, U1.64 (IOB_104_CBSEL1)
/CDONE: J1.2; also elsewhere on the board
/D0: U1.31 (IOL_24A); also elsewhere on the board
/D1: U1.32 (IOL_24B); also elsewhere on the board
/D2: U1.33 (IOL_25A); also elsewhere on the board
/D3: U1.34 (IOL_25B); also elsewhere on the board
/D4: U1.37 (IOB_56); also elsewhere on the board
/D5: U1.38 (IOB_57); also elsewhere on the board
/D6: U1.39 (IOB_61); also elsewhere on the board
/D7: U1.41 (IOB_63); also elsewhere on the board
/G0: U1.83 (IOR_119); also elsewhere on the board
/G1: U1.84 (IOR_120); also elsewhere on the board
/G2: U1.85 (IOR_128); also elsewhere on the board
/G3: U1.87 (IOR_136); also elsewhere on the board
/G4: U1.88 (IOR_137); also elsewhere on the board
/G5: U1.90 (IOR_138); also elsewhere on the board
/G6: U1.91 (IOR_139); also elsewhere on the board
/GREEN: U1.56 (IOB_94), U3.33 (2A2)
/GREEN2: U1.74 (IOR_110), U3.26 (2A7)
/GREEN2_5V: J4.6, U3.23 (2B7)
/GREEN_5V: J4.4, U3.16 (2B2)
/HSYNC: U1.60 (IOB_95), U3.32 (2A3)
/HSYNC_5V: J4.8, U3.17 (2B3)
/OSC10M: R6.2, U1.49 (IOB_81_GBIN5)
/OSC14M318: R11.2, R25.2, U1.129 (IOT_198_GBIN0)
/OSC_14M318_5V: U3.8 (1B4); also elsewhere on the board
/R0: U1.93 (IOR_140_GBIN3); also elsewhere on the board
/R1: U1.94 (IOR_141_GBIN2); also elsewhere on the board
/R2: U1.95 (IOR_144); also elsewhere on the board
/R3: U1.96 (IOR_146); also elsewhere on the board
/R4: U1.97 (IOR_147); also elsewhere on the board
/R5: U1.98 (IOR_148); also elsewhere on the board
/RA0: U1.105 (IOR_165); also elsewhere on the board
/RA1: U1.106 (IOR_166); also elsewhere on the board
/RA2: U1.110 (IOT_168); also elsewhere on the board
/RA3: U1.113 (IOT_170); also elsewhere on the board
/RA4: U1.115 (IOT_172); also elsewhere on the board
/RA5: U1.135 (IOT_213); also elsewhere on the board
/RA6: U1.137 (IOT_215); also elsewhere on the board
/RA7: U1.139 (IOT_217); also elsewhere on the board
/RA8: U1.142 (IOT_220); also elsewhere on the board
/RA9: U1.144 (IOT_222); also elsewhere on the board
/RA10: U1.143 (IOT_221); also elsewhere on the board
/RA11: U1.141 (IOT_219); also elsewhere on the board
/RA12: U1.138 (IOT_216); also elsewhere on the board
/RA13: U1.136 (IOT_214); also elsewhere on the board
/RA14: U1.134 (IOT_212); also elsewhere on the board
/RA15: U1.116 (IOT_173); also elsewhere on the board
/RA16: U1.114 (IOT_171); also elsewhere on the board
/RA17: U1.112 (IOT_169); also elsewhere on the board
/RA18: U1.107 (IOR_167); also elsewhere on the board
/RAM/~RAM_WE: U1.130 (IOT_206); also elsewhere on the board
/RD0: U1.117 (IOT_174); also elsewhere on the board
/RD1: U1.119 (IOT_178); also elsewhere on the board
/RD2: U1.121 (IOT_181); also elsewhere on the board
/RD3: U1.124 (IOT_191); also elsewhere on the board
/RD4: U1.125 (IOT_192); also elsewhere on the board
/RD5: U1.122 (IOT_190); also elsewhere on the board
/RD6: U1.120 (IOT_179); also elsewhere on the board
/RD7: U1.118 (IOT_177); also elsewhere on the board
/RED: U1.61 (IOB_96), U3.30 (2A4)
/RED2: U1.73 (IOR_109), U3.27 (2A6)
/RED2_5V: R12.2, U3.22 (2B6)
/RED_5V: J4.3, U3.19 (2B4)
/RESET_5V: U3.2 (1B0); also elsewhere on the board
/SPI_CIPO: J1.5, U1.68 (IOB_106_SDI), U2.2 (MISO)
/SPI_COPI: J1.7, U1.67 (IOB_105_SDO), U2.5 (MOSI)
/SPI_SCK: J1.3, R8.2, U1.70 (IOB_107_SCK), U2.6 (SCK)
/SPI_~CS: J1.1, R1.2, U1.71 (IOB_108_SS), U2.1 (~CS)
/SW2: R23.1, SW1.3, U1.101 (IOR_160)
/SW3: R24.1, SW1.4, U1.99 (IOR_152)
/VGA_HSYNC: U1.102 (IOR_161), U11.2
/VGA_HSYNC_5V: J2.13, U11.3
/VGA_VSYNC: U1.104 (IOR_164), U11.5
/VGA_VSYNC_5V: J2.14, U11.6
/VID_EN: U1.75 (IOR_111), U3.25 (2~OE)
/VSYNC: U1.55 (IOB_91), U3.35 (2A1)
/VSYNC_5V: J4.9, U3.14 (2B1)
/vga_dac/COMPOSITE: J3.1 (In), J6.3; also elsewhere on the board
/~CRESET: J1.4; also elsewhere on the board
/~IOR: U1.25 (IOL_18A); also elsewhere on the board
/~IOW: U1.26 (IOL_18B); also elsewhere on the board
/~SMEMR: U1.28 (IOL_23A); also elsewhere on the board
/~SMEMW: U1.29 (IOL_23B); also elsewhere on the board
GND: C1.2, C20.2, C21.2, C22.2, C30.2, C31.2, J1.6, J2.5, J2.6, J2.7, J2.8, J2.10, J2.SH (Shield), J3.2 (Ext), J4.1, J4.SH (Shield), J6.4, R4.2, R5.2, R23.2, R24.2, U2.4 (GND), U3.1 (1DIR), U3.4 (GND), U3.9 (1B5), U3.10 (GND), U3.11 (1B6), U3.12 (1B7), U3.15 (GND), U3.21 (GND), U3.28 (GND), U3.34 (GND), U3.39 (GND), U3.45 (GND), U3.48 (2~OE), U11.1, U11.4, U11.7 (GND), X1.2 (GND), X2.2 (GND); also elsewhere on the board
unnamed: C1.1, R7.2, R9.1, X1.4 (Vdd)
unnamed: C30.1, R26.2, R27.1, X2.4 (Vdd)
unnamed: F1.1, J2.9
unnamed: J4.2, R12.1
unnamed: R2.2, U2.7 (~HOLD)
unnamed: R3.2, U2.3 (~WP)
unnamed: R6.1, X1.3 (OUT)
unnamed: R9.2, X1.1 (EN)
unnamed: R10.1, U3.44 (1A2)
unnamed: R11.1, U3.41 (1A4)
unnamed: R25.1, X2.3 (OUT)
unnamed: R27.2, X2.1 (EN)

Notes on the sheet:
135183 BYTES USED FOR BITSTREAM CAN STORE VIDEO BIOS IN EXTRA SPACE
VIDEO
INTENSITY
GND
108
109
144
10MHz MIN 133MHz MAX
FPGA PIN PLAN
This work is licensed under the Creative Commons Attribution-ShareAlike 4.0 International License. To view a copy of this license, visit http://creativecommons.org/licenses/by-sa/4.0/ or send a letter to Creative Commons, PO Box 1866, Mountain View, CA 94042, USA.
GRAPHICS GREMLIN
DESIGN BY @TubeTimeUS
STUFF R25 FOR ONBOARD 14.318MHZ STUFF R11 FOR ISA BUS 14.318MHZ

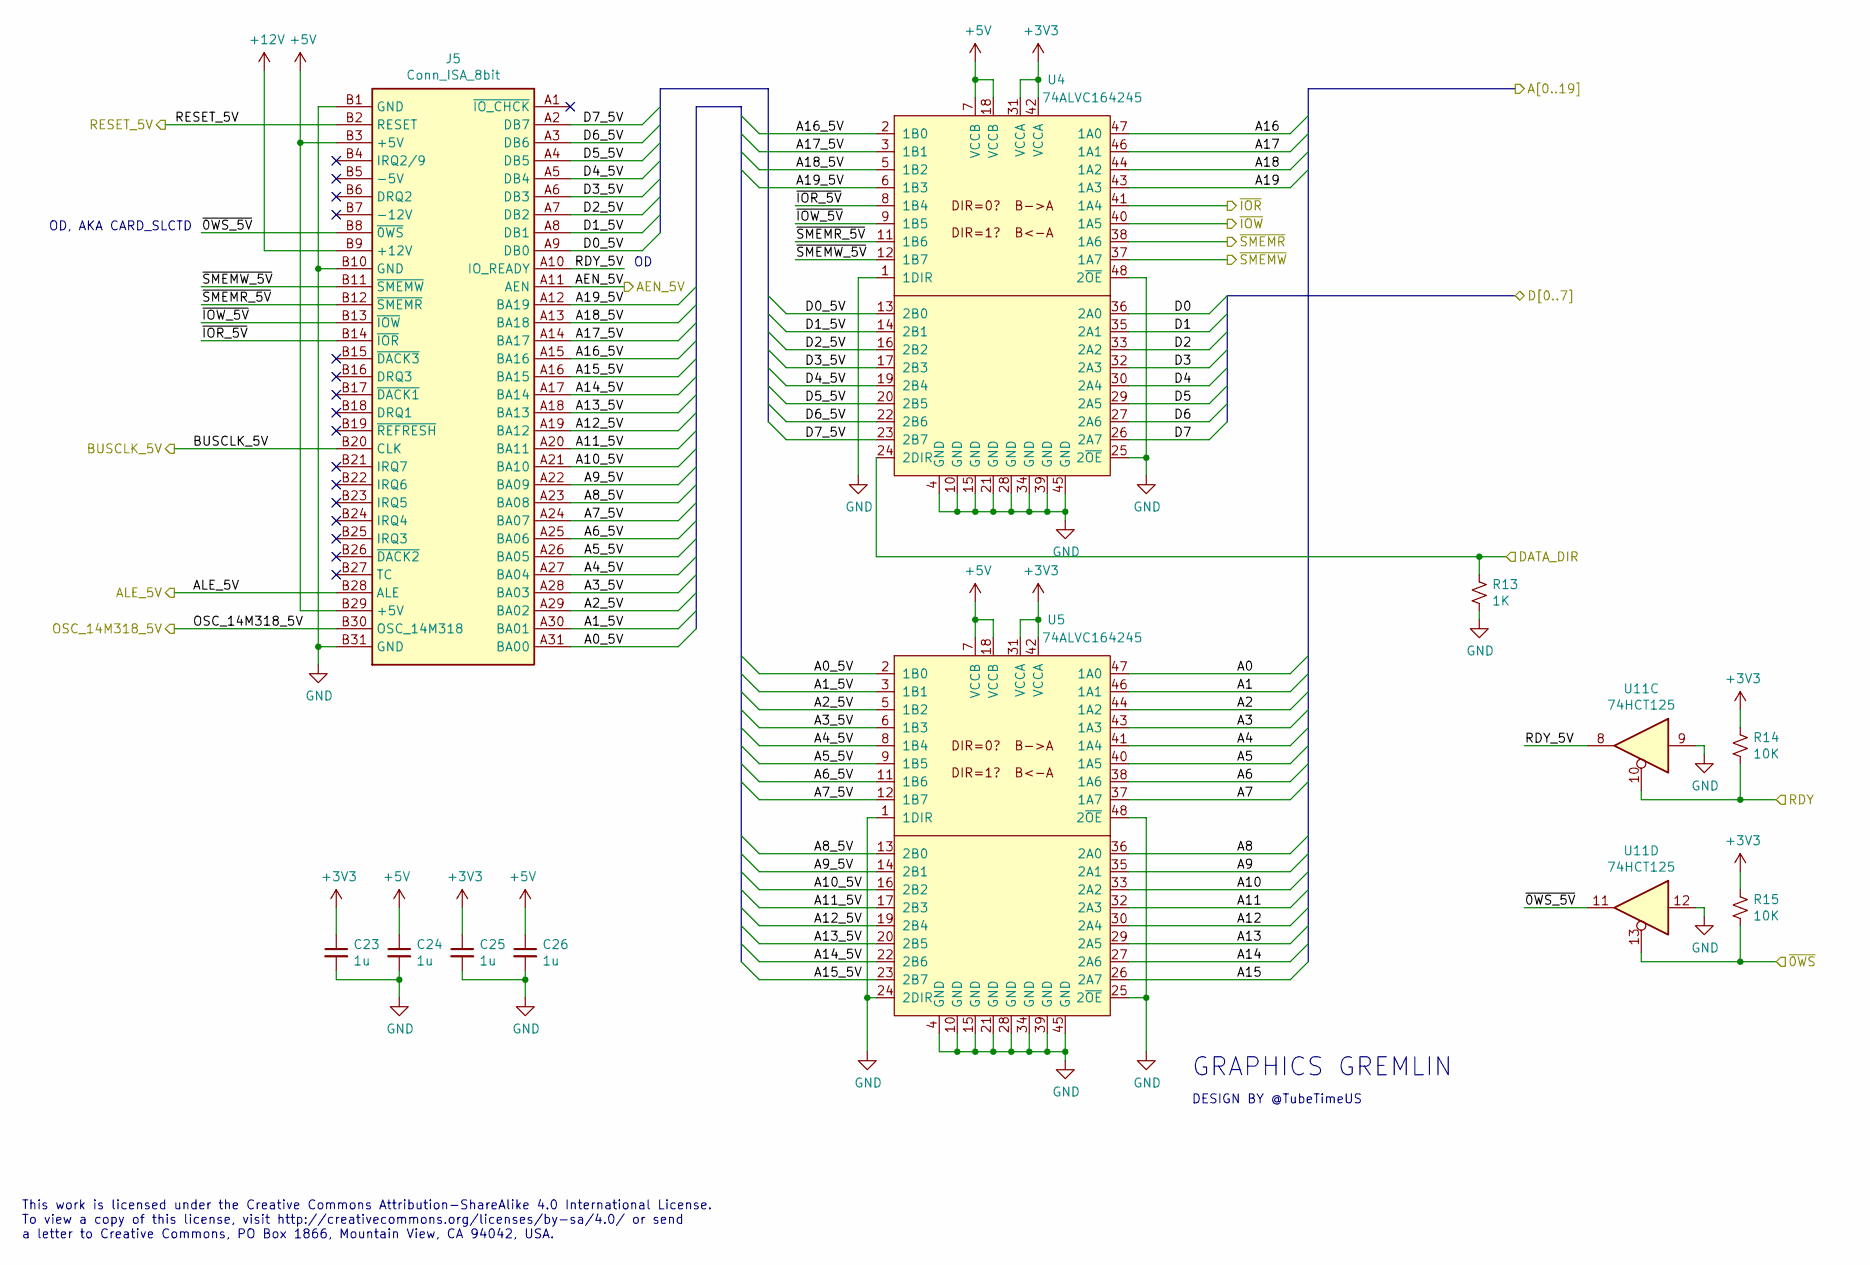
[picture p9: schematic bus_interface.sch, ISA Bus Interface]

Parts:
C23, C24, C25, C26: 1u; CAPC1608X100; Mouser 810-CGA3E1X7R1C105AC
J5: Conn_ISA_8bit; BUS_PC_8BIT
R13: 1K; RESC1608X55; Mouser 603-RC0603FR-071KL
R14, R15: 10K; RESC1608X55; Mouser 603-RC0603FR-0710KL
U4, U5: 74ALVC164245; TSSOP50P810X120-48; Mouser 771-74ALVC164245
U11: 74HCT125; TSOP65P640X110-14; Mouser 771-74HCT125PW-T

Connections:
+3V3: C23.1, C25.1, R14.1, R15.1, U4.31 (VCCA), U4.42 (VCCA), U5.31 (VCCA), U5.42 (VCCA); also elsewhere on the board
+5V: C24.1, C26.1, J5.B3 (+5V), J5.B29 (+5V), U4.7 (VCCB), U4.18 (VCCB), U5.7 (VCCB), U5.18 (VCCB); also elsewhere on the board
+12V: J5.B9 (+12V); also elsewhere on the board
/A0: U5.47 (1A0); also elsewhere on the board
/A1: U5.46 (1A1); also elsewhere on the board
/A2: U5.44 (1A2); also elsewhere on the board
/A3: U5.43 (1A3); also elsewhere on the board
/A4: U5.41 (1A4); also elsewhere on the board
/A5: U5.40 (1A5); also elsewhere on the board
/A6: U5.38 (1A6); also elsewhere on the board
/A7: U5.37 (1A7); also elsewhere on the board
/A8: U5.36 (2A0); also elsewhere on the board
/A9: U5.35 (2A1); also elsewhere on the board
/A10: U5.33 (2A2); also elsewhere on the board
/A11: U5.32 (2A3); also elsewhere on the board
/A12: U5.30 (2A4); also elsewhere on the board
/A13: U5.29 (2A5); also elsewhere on the board
/A14: U5.27 (2A6); also elsewhere on the board
/A15: U5.26 (2A7); also elsewhere on the board
/A16: U4.47 (1A0); also elsewhere on the board
/A17: U4.46 (1A1); also elsewhere on the board
/A18: U4.44 (1A2); also elsewhere on the board
/A19: U4.43 (1A3); also elsewhere on the board
/AEN_5V: J5.A11 (AEN); also elsewhere on the board
/ALE_5V: J5.B28 (ALE); also elsewhere on the board
/BUSCLK_5V: J5.B20 (CLK); also elsewhere on the board
/Bus Interface/A0_5V: J5.A31 (BA00), U5.2 (1B0)
/Bus Interface/A1_5V: J5.A30 (BA01), U5.3 (1B1)
/Bus Interface/A2_5V: J5.A29 (BA02), U5.5 (1B2)
/Bus Interface/A3_5V: J5.A28 (BA03), U5.6 (1B3)
/Bus Interface/A4_5V: J5.A27 (BA04), U5.8 (1B4)
/Bus Interface/A5_5V: J5.A26 (BA05), U5.9 (1B5)
/Bus Interface/A6_5V: J5.A25 (BA06), U5.11 (1B6)
/Bus Interface/A7_5V: J5.A24 (BA07), U5.12 (1B7)
/Bus Interface/A8_5V: J5.A23 (BA08), U5.13 (2B0)
/Bus Interface/A9_5V: J5.A22 (BA09), U5.14 (2B1)
/Bus Interface/A10_5V: J5.A21 (BA10), U5.16 (2B2)
/Bus Interface/A11_5V: J5.A20 (BA11), U5.17 (2B3)
/Bus Interface/A12_5V: J5.A19 (BA12), U5.19 (2B4)
/Bus Interface/A13_5V: J5.A18 (BA13), U5.20 (2B5)
/Bus Interface/A14_5V: J5.A17 (BA14), U5.22 (2B6)
/Bus Interface/A15_5V: J5.A16 (BA15), U5.23 (2B7)
/Bus Interface/A16_5V: J5.A15 (BA16), U4.2 (1B0)
/Bus Interface/A17_5V: J5.A14 (BA17), U4.3 (1B1)
/Bus Interface/A18_5V: J5.A13 (BA18), U4.5 (1B2)
/Bus Interface/A19_5V: J5.A12 (BA19), U4.6 (1B3)
/Bus Interface/D0_5V: J5.A9 (DB0), U4.13 (2B0)
/Bus Interface/D1_5V: J5.A8 (DB1), U4.14 (2B1)
/Bus Interface/D2_5V: J5.A7 (DB2), U4.16 (2B2)
/Bus Interface/D3_5V: J5.A6 (DB3), U4.17 (2B3)
/Bus Interface/D4_5V: J5.A5 (DB4), U4.19 (2B4)
/Bus Interface/D5_5V: J5.A4 (DB5), U4.20 (2B5)
/Bus Interface/D6_5V: J5.A3 (DB6), U4.22 (2B6)
/Bus Interface/D7_5V: J5.A2 (DB7), U4.23 (2B7)
/Bus Interface/DATA_DIR: R13.1, U4.24 (2DIR); also elsewhere on the board
/Bus Interface/RDY: R14.2, U11.10; also elsewhere on the board
/Bus Interface/RDY_5V: J5.A10 (IO_READY), U11.8
/Bus Interface/~0WS: R15.2, U11.13; also elsewhere on the board
/Bus Interface/~0WS_5V: J5.B8 (~0WS), U11.11
/Bus Interface/~IOR_5V: J5.B14 (~IOR), U4.8 (1B4)
/Bus Interface/~IOW_5V: J5.B13 (~IOW), U4.9 (1B5)
/Bus Interface/~SMEMR_5V: J5.B12 (~SMEMR), U4.11 (1B6)
/Bus Interface/~SMEMW_5V: J5.B11 (~SMEMW), U4.12 (1B7)
/D0: U4.36 (2A0); also elsewhere on the board
/D1: U4.35 (2A1); also elsewhere on the board
/D2: U4.33 (2A2); also elsewhere on the board
/D3: U4.32 (2A3); also elsewhere on the board
/D4: U4.30 (2A4); also elsewhere on the board
/D5: U4.29 (2A5); also elsewhere on the board
/D6: U4.27 (2A6); also elsewhere on the board
/D7: U4.26 (2A7); also elsewhere on the board
/OSC_14M318_5V: J5.B30 (OSC_14M318); also elsewhere on the board
/RESET_5V: J5.B2 (RESET); also elsewhere on the board
/~IOR: U4.41 (1A4); also elsewhere on the board
/~IOW: U4.40 (1A5); also elsewhere on the board
/~SMEMR: U4.38 (1A6); also elsewhere on the board
/~SMEMW: U4.37 (1A7); also elsewhere on the board
GND: C23.2, C24.2, C25.2, C26.2, J5.B1 (GND), J5.B10 (GND), J5.B31 (GND), R13.2, U4.1 (1DIR), U4.4 (GND), U4.10 (GND), U4.15 (GND), U4.21 (GND), U4.25 (2~OE), U4.28 (GND), U4.34 (GND), U4.39 (GND), U4.45 (GND), U4.48 (2~OE), U5.1 (1DIR), U5.4 (GND), U5.10 (GND), U5.15 (GND), U5.21 (GND), U5.24 (2DIR), U5.25 (2~OE), U5.28 (GND), U5.34 (GND), U5.39 (GND), U5.45 (GND), U5.48 (2~OE), U11.9, U11.12; also elsewhere on the board

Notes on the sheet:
OD, AKA CARD_SLCTD
This work is licensed under the Creative Commons Attribution-ShareAlike 4.0 International License. To view a copy of this license, visit http://creativecommons.org/licenses/by-sa/4.0/ or send a letter to Creative Commons, PO Box 1866, Mountain View, CA 94042, USA.
GRAPHICS GREMLIN
DESIGN BY @TubeTimeUS

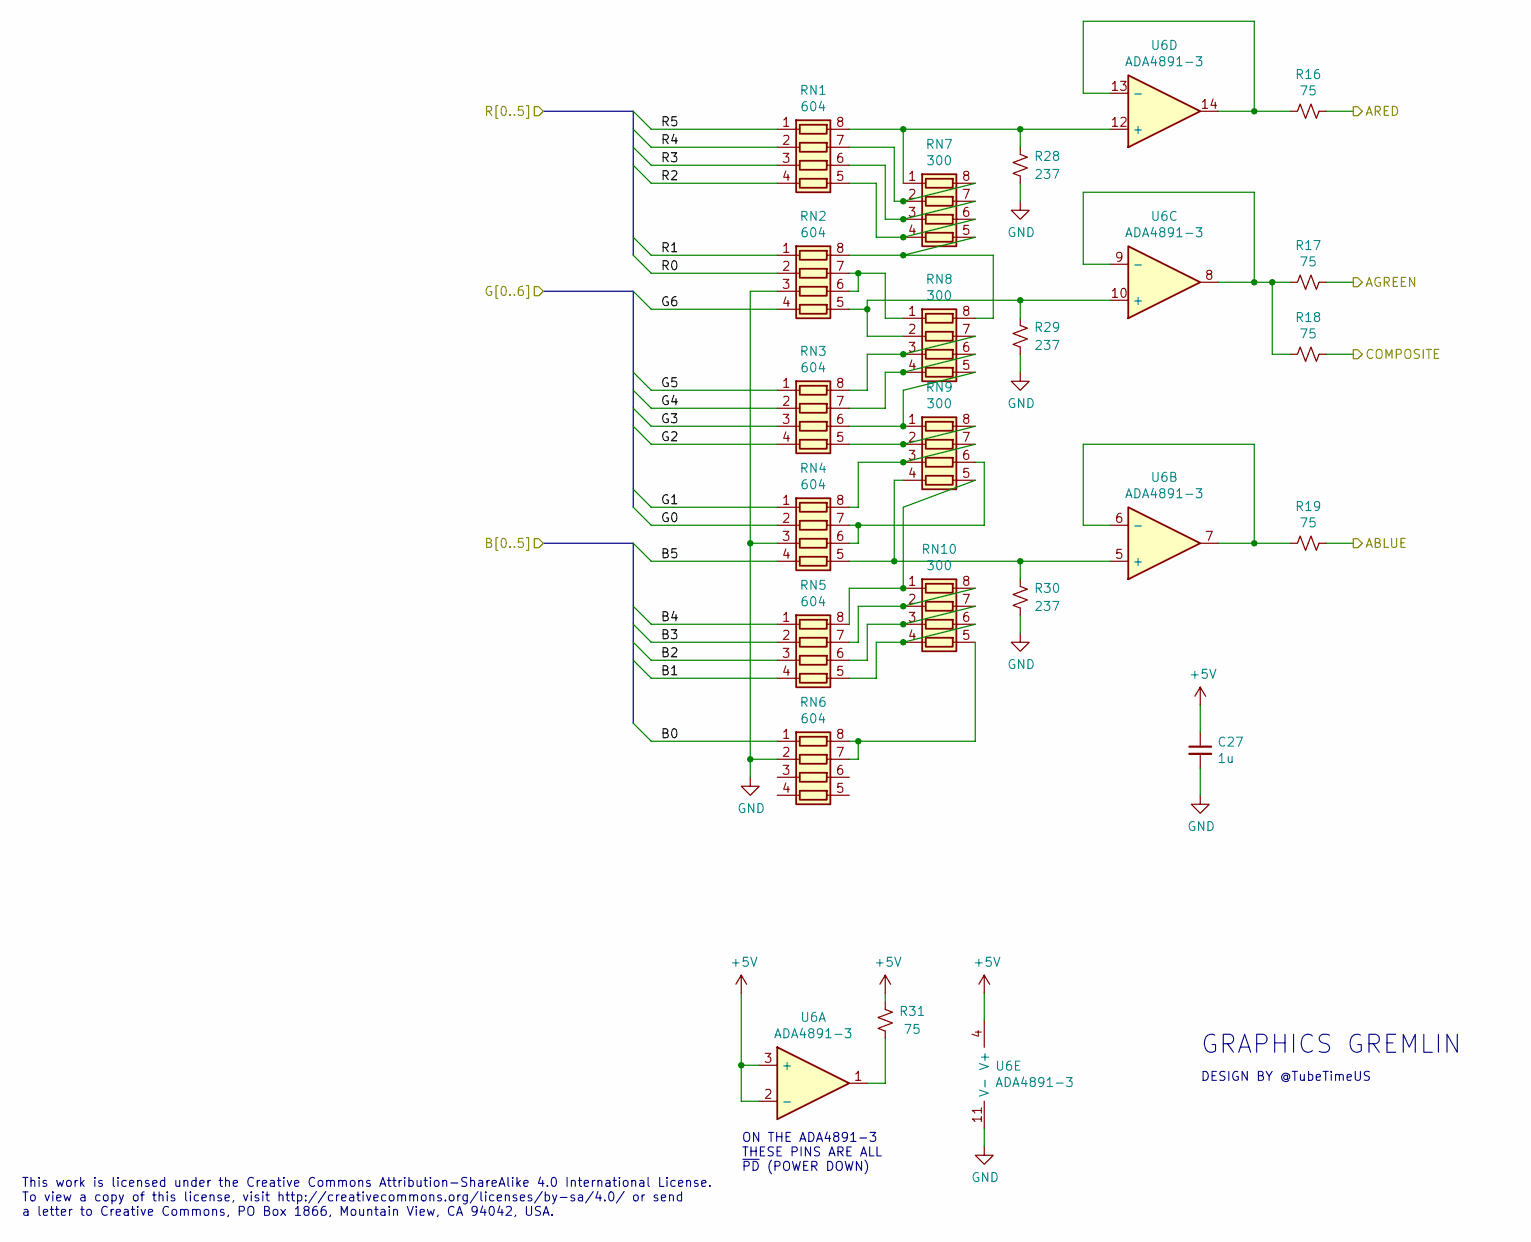
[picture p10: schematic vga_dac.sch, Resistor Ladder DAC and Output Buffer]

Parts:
C27: 1u; CAPC1608X100; Mouser 810-CGA3E1X7R1C105AC
R16, R17, R18, R19, R31: 75; RESC1608X55; Mouser 603-RC0603FR-0775RL
R28, R29, R30: 237; RESC1608X55; Mouser 603-RC0603FR-07237RL
RN1, RN2, RN3, RN4, RN5, RN6: 604; RESCAV80P320X160X70-8; Mouser 652-CAY16-6040F4LF
RN7, RN8, RN9, RN10: 300; RESCAV80P320X160X70-8; Mouser 652-CAY16-3000F4LF
U6: ADA4891-3; SOP127P620X175-14; Mouser 584-ADA4891-3ARZ

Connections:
+5V: C27.1, R31.2, U6.2 (-), U6.3 (+), U6.4 (V+); also elsewhere on the board
/ABLUE: R19.1; also elsewhere on the board
/AGREEN: R17.1; also elsewhere on the board
/ARED: R16.1; also elsewhere on the board
/B0: RN6.1 (R1.1); also elsewhere on the board
/B1: RN5.4 (R4.1); also elsewhere on the board
/B2: RN5.3 (R3.1); also elsewhere on the board
/B3: RN5.2 (R2.1); also elsewhere on the board
/B4: RN5.1 (R1.1); also elsewhere on the board
/B5: RN4.4 (R4.1); also elsewhere on the board
/G0: RN4.2 (R2.1); also elsewhere on the board
/G1: RN4.1 (R1.1); also elsewhere on the board
/G2: RN3.4 (R4.1); also elsewhere on the board
/G3: RN3.3 (R3.1); also elsewhere on the board
/G4: RN3.2 (R2.1); also elsewhere on the board
/G5: RN3.1 (R1.1); also elsewhere on the board
/G6: RN2.4 (R4.1); also elsewhere on the board
/R0: RN2.2 (R2.1); also elsewhere on the board
/R1: RN2.1 (R1.1); also elsewhere on the board
/R2: RN1.4 (R4.1); also elsewhere on the board
/R3: RN1.3 (R3.1); also elsewhere on the board
/R4: RN1.2 (R2.1); also elsewhere on the board
/R5: RN1.1 (R1.1); also elsewhere on the board
/vga_dac/COMPOSITE: R18.1; also elsewhere on the board
GND: C27.2, R28.1, R29.1, R30.1, RN2.3 (R3.1), RN4.3 (R3.1), RN6.2 (R2.1), U6.11 (V-); also elsewhere on the board
unnamed: R16.2, U6.13 (-), U6.14
unnamed: R17.2, R18.2, U6.8, U6.9 (-)
unnamed: R19.2, U6.6 (-), U6.7
unnamed: R28.2, RN1.8 (R1.2), RN7.1 (R1.1), U6.12 (+)
unnamed: R29.2, RN2.5 (R4.2), RN8.2 (R2.1), U6.10 (+)
unnamed: R30.2, RN4.5 (R4.2), RN9.4 (R4.1), U6.5 (+)
unnamed: R31.1, U6.1
unnamed: RN1.5 (R4.2), RN7.4 (R4.1), RN7.6 (R3.2)
unnamed: RN1.6 (R3.2), RN7.3 (R3.1), RN7.7 (R2.2)
unnamed: RN1.7 (R2.2), RN7.2 (R2.1), RN7.8 (R1.2)
unnamed: RN2.6 (R3.2), RN2.7 (R2.2), RN8.1 (R1.1)
unnamed: RN2.8 (R1.2), RN7.5 (R4.2), RN8.8 (R1.2)
unnamed: RN3.5 (R4.2), RN9.2 (R2.1), RN9.8 (R1.2)
unnamed: RN3.6 (R3.2), RN8.5 (R4.2), RN9.1 (R1.1)
unnamed: RN3.7 (R2.2), RN8.4 (R4.1), RN8.6 (R3.2)
unnamed: RN3.8 (R1.2), RN8.3 (R3.1), RN8.7 (R2.2)
unnamed: RN4.6 (R3.2), RN4.7 (R2.2), RN9.6 (R3.2)
unnamed: RN4.8 (R1.2), RN9.3 (R3.1), RN9.7 (R2.2)
unnamed: RN5.8 (R1.2), RN9.5 (R4.2), RN10.1 (R1.1)
unnamed: RN5.7 (R2.2), RN10.2 (R2.1), RN10.8 (R1.2)
unnamed: RN5.6 (R3.2), RN10.3 (R3.1), RN10.7 (R2.2)
unnamed: RN5.5 (R4.2), RN10.4 (R4.1), RN10.6 (R3.2)
unnamed: RN6.7 (R2.2), RN6.8 (R1.2), RN10.5 (R4.2)

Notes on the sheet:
ON THE ADA4891-3 THESE PINS ARE ALL ~PD~ (POWER DOWN)
GRAPHICS GREMLIN
DESIGN BY @TubeTimeUS
This work is licensed under the Creative Commons Attribution-ShareAlike 4.0 International License. To view a copy of this license, visit http://creativecommons.org/licenses/by-sa/4.0/ or send a letter to Creative Commons, PO Box 1866, Mountain View, CA 94042, USA.

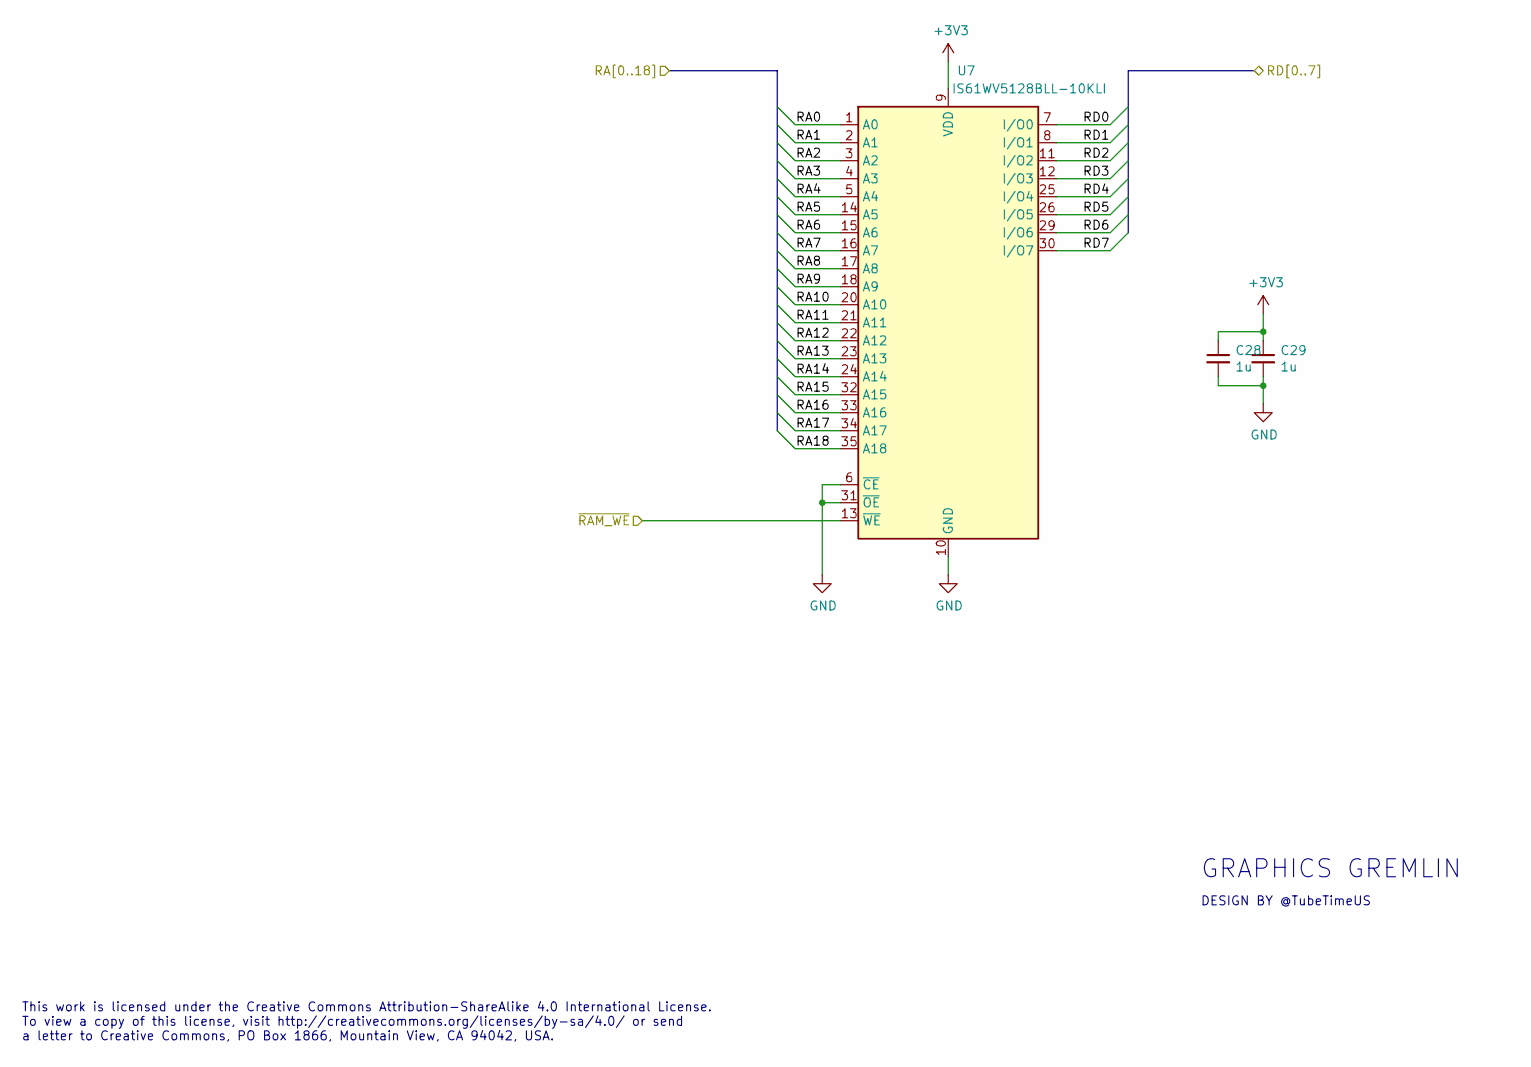
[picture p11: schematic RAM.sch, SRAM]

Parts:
C28, C29: 1u; CAPC1608X100; Mouser 810-CGA3E1X7R1C105AC
U7: IS61WV5128BLL-10KLI; SOJ127P1118X376-36; Mouser 870-61WV5128B10KLI

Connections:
+3V3: C28.1, C29.1, U7.9 (VDD), U7.27 (VDD); also elsewhere on the board
/RA0: U7.1 (A0); also elsewhere on the board
/RA1: U7.2 (A1); also elsewhere on the board
/RA2: U7.3 (A2); also elsewhere on the board
/RA3: U7.4 (A3); also elsewhere on the board
/RA4: U7.5 (A4); also elsewhere on the board
/RA5: U7.14 (A5); also elsewhere on the board
/RA6: U7.15 (A6); also elsewhere on the board
/RA7: U7.16 (A7); also elsewhere on the board
/RA8: U7.17 (A8); also elsewhere on the board
/RA9: U7.18 (A9); also elsewhere on the board
/RA10: U7.20 (A10); also elsewhere on the board
/RA11: U7.21 (A11); also elsewhere on the board
/RA12: U7.22 (A12); also elsewhere on the board
/RA13: U7.23 (A13); also elsewhere on the board
/RA14: U7.24 (A14); also elsewhere on the board
/RA15: U7.32 (A15); also elsewhere on the board
/RA16: U7.33 (A16); also elsewhere on the board
/RA17: U7.34 (A17); also elsewhere on the board
/RA18: U7.35 (A18); also elsewhere on the board
/RAM/~RAM_WE: U7.13 (~WE); also elsewhere on the board
/RD0: U7.7 (I/O0); also elsewhere on the board
/RD1: U7.8 (I/O1); also elsewhere on the board
/RD2: U7.11 (I/O2); also elsewhere on the board
/RD3: U7.12 (I/O3); also elsewhere on the board
/RD4: U7.25 (I/O4); also elsewhere on the board
/RD5: U7.26 (I/O5); also elsewhere on the board
/RD6: U7.29 (I/O6); also elsewhere on the board
/RD7: U7.30 (I/O7); also elsewhere on the board
GND: C28.2, C29.2, U7.6 (~CE), U7.10 (GND), U7.28 (GND), U7.31 (~OE); also elsewhere on the board

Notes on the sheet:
GRAPHICS GREMLIN
DESIGN BY @TubeTimeUS
This work is licensed under the Creative Commons Attribution-ShareAlike 4.0 International License. To view a copy of this license, visit http://creativecommons.org/licenses/by-sa/4.0/ or send a letter to Creative Commons, PO Box 1866, Mountain View, CA 94042, USA.

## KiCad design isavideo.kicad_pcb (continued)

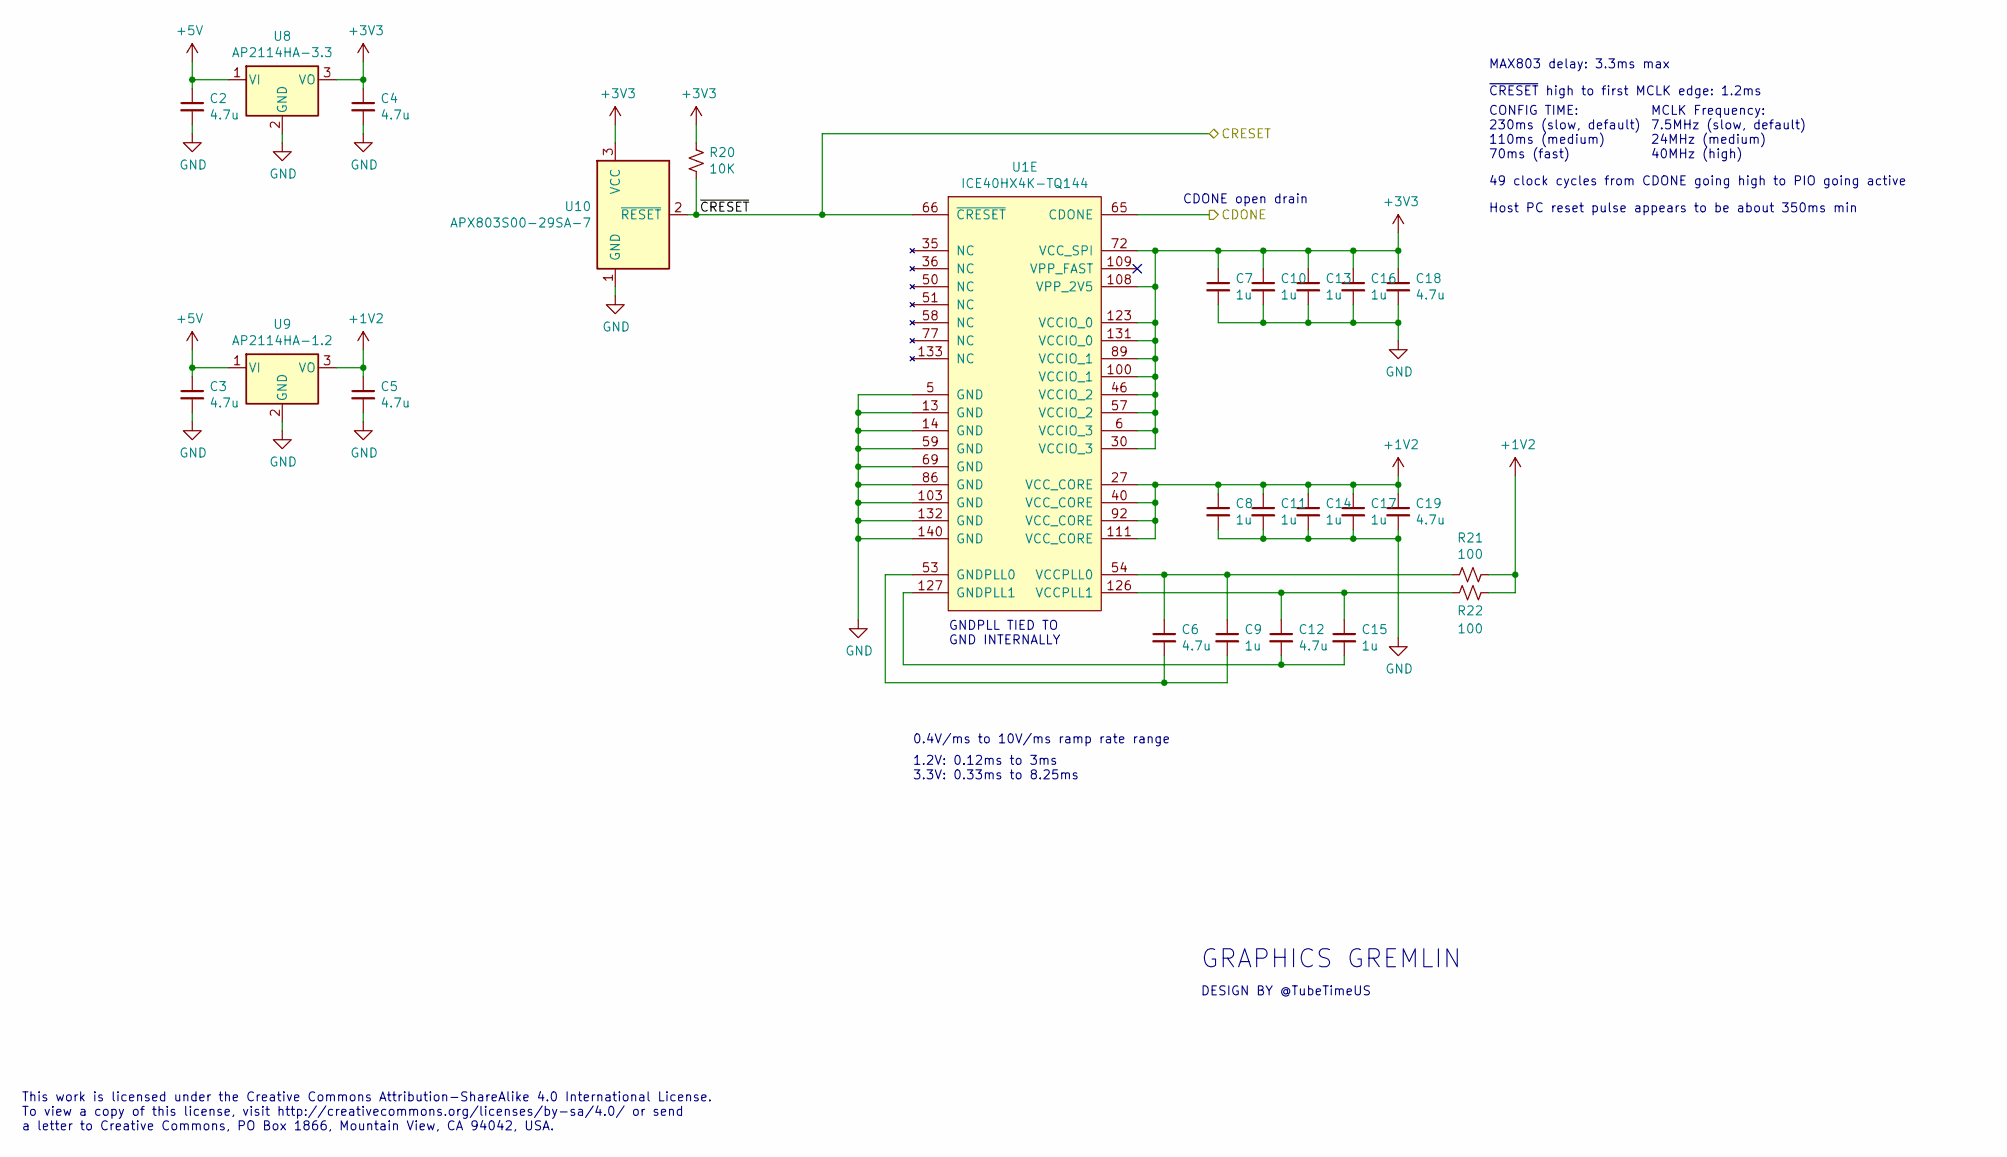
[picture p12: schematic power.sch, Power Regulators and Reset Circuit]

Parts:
C2, C3, C4, C5, C6, C12, C18, C19: 4.7u; CAPC1608X100; Mouser 187-CL10A475KP8NNNC
C7, C8, C9, C10, C11, C13, C14, C15, C16, C17: 1u; CAPC1608X100; Mouser 810-CGA3E1X7R1C105AC
R20: 10K; RESC1608X55; Mouser 603-RC0603FR-0710KL
R21, R22: 100; RESC1608X55; Mouser 603-RC0603FR-07100RL
U1: ICE40HX4K-TQ144; TSQFP50P2200X2200X160-144; Mouser 842-ICE40HX4K-TQ144
U8: AP2114HA-3.3; SOT230P700X170-3; Mouser 621-AP2114HA-3.3TRG1
U9: AP2114HA-1.2; SOT230P700X170-3; Mouser 621-AP2114HA-1.2TRG1
U10: APX803S00-29SA-7; SOT95P230X117-3; Mouser 621-APX803S00-29SA-7

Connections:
+1V2: C5.1, C8.1, C11.1, C14.1, C17.1, C19.1, R21.1, R22.1, U1.27 (VCC_CORE), U1.40 (VCC_CORE), U1.92 (VCC_CORE), U1.111 (VCC_CORE), U9.3 (VO)
+3V3: C4.1, C7.1, C10.1, C13.1, C16.1, C18.1, R20.1, U1.6 (VCCIO_3), U1.30 (VCCIO_3), U1.46 (VCCIO_2), U1.57 (VCCIO_2), U1.72 (VCC_SPI), U1.89 (VCCIO_1), U1.100 (VCCIO_1), U1.108 (VPP_2V5), U1.123 (VCCIO_0), U1.131 (VCCIO_0), U8.3 (VO), U10.3 (VCC); also elsewhere on the board
+5V: C2.1, C3.1, U8.1 (VI), U9.1 (VI); also elsewhere on the board
/CDONE: U1.65 (CDONE); also elsewhere on the board
/~CRESET: R20.2, U1.66 (~CRESET), U10.2 (~RESET~); also elsewhere on the board
GND: C2.2, C3.2, C4.2, C5.2, C7.2, C8.2, C10.2, C11.2, C13.2, C14.2, C16.2, C17.2, C18.2, C19.2, U1.5 (GND), U1.13 (GND), U1.14 (GND), U1.59 (GND), U1.69 (GND), U1.86 (GND), U1.103 (GND), U1.132 (GND), U1.140 (GND), U8.2 (GND), U9.2 (GND), U10.1 (GND); also elsewhere on the board
unnamed: C6.1, C9.1, R21.2, U1.54 (VCCPLL0)
unnamed: C6.2, C9.2, U1.53 (GNDPLL0)
unnamed: C12.1, C15.1, R22.2, U1.126 (VCCPLL1)
unnamed: C12.2, C15.2, U1.127 (GNDPLL1)

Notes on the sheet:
CDONE open drain
GNDPLL TIED TO GND INTERNALLY
CONFIG TIME: 230ms (slow, default) 110ms (medium) 70ms (fast)
49 clock cycles from CDONE going high to PIO going active
MCLK Frequency: 7.5MHz (slow, default) 24MHz (medium) 40MHz (high)
~CRESET~ high to first MCLK edge: 1.2ms
0.4V/ms to 10V/ms ramp rate range
1.2V: 0.12ms to 3ms 3.3V: 0.33ms to 8.25ms
MAX803 delay: 3.3ms max
Host PC reset pulse appears to be about 350ms min
GRAPHICS GREMLIN
DESIGN BY @TubeTimeUS
This work is licensed under the Creative Commons Attribution-ShareAlike 4.0 International License. To view a copy of this license, visit http://creativecommons.org/licenses/by-sa/4.0/ or send a letter to Creative Commons, PO Box 1866, Mountain View, CA 94042, USA.

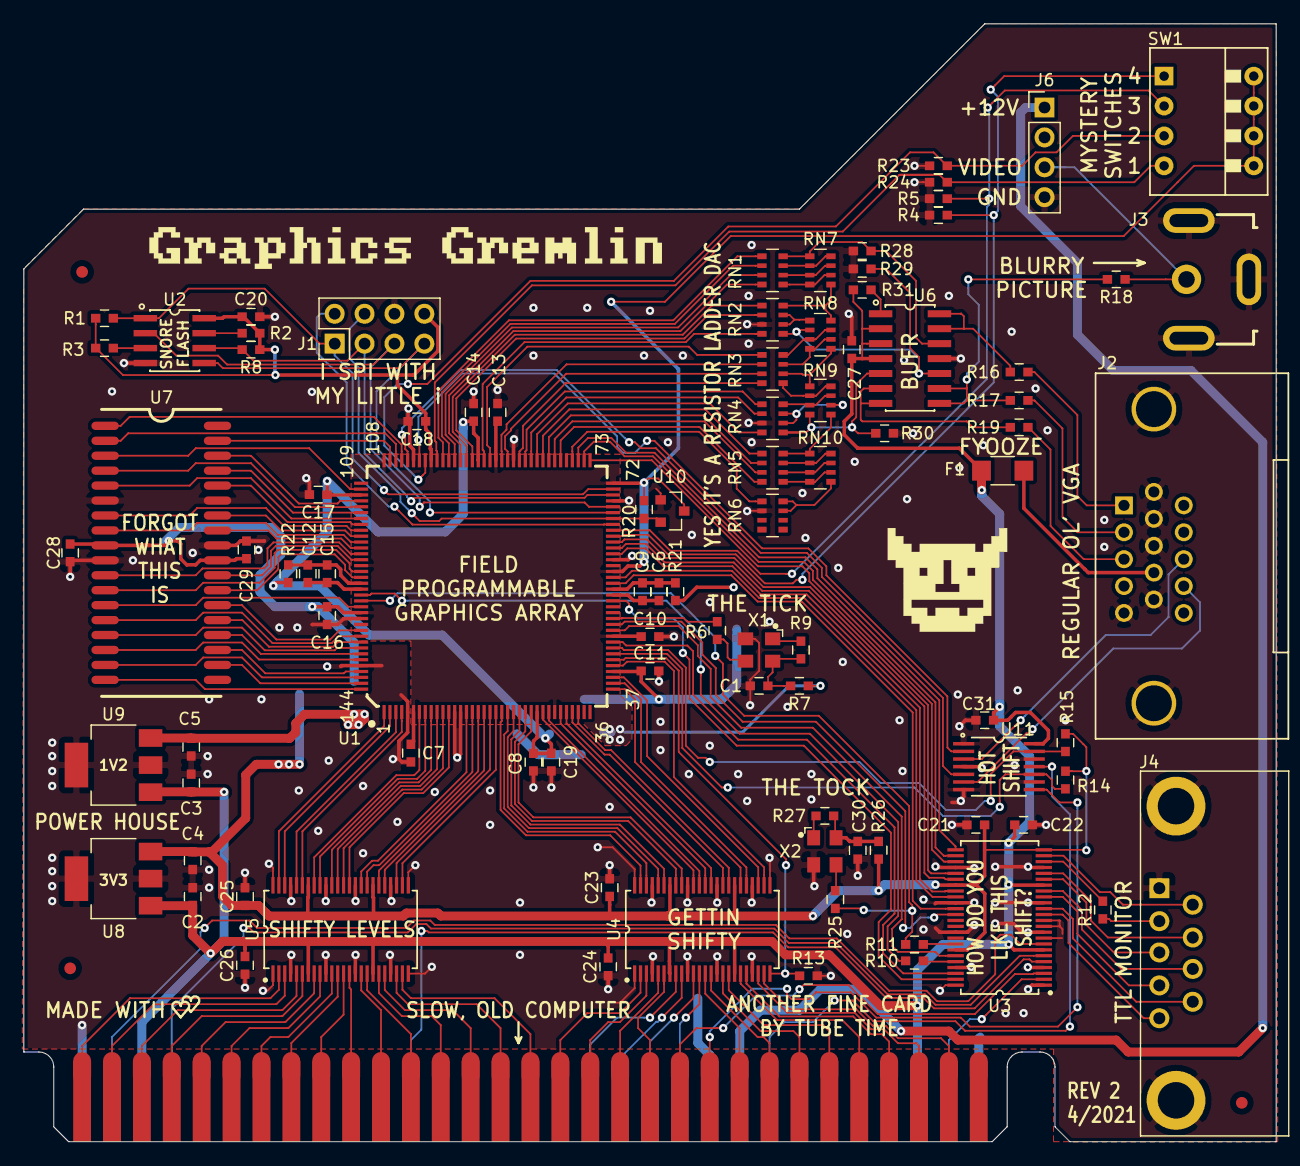
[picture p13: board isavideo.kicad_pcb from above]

Board: 2 copper layers, 106.4 x 95.0 mm, 97 parts (0 on the bottom side), 206 nets.

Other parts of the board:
MH1: MNT_KEYSTONE_9200

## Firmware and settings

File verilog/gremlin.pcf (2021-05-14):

### Graphics Gremlin

### Copyright (c) 2021 Eric Schlaepfer
### This work is licensed under the Creative Commons Attribution-ShareAlike 4.0
### International License. To view a copy of this license, visit
### http://creativecommons.org/license/by-sa/4.0/ or send a letter to Creative
### Commons, PO Box 1866, Mountain View, CA 94042, USA.

### Clocks
set_io clk_14m318   129
set_io clk_10m      49
set_io clk_bus      128

### Bus reset
set_io busreset     52

### ISA bus
set_io bus_a[0]     1
set_io bus_a[1]     2
set_io bus_a[2]     3
set_io bus_a[3]     4
set_io bus_a[4]     7
set_io bus_a[5]     8
set_io bus_a[6]     9
set_io bus_a[7]     10
set_io bus_a[8]     11
set_io bus_a[9]     12
set_io bus_a[10]    15
set_io bus_a[11]    16
set_io bus_a[12]    17
set_io bus_a[13]    18
set_io bus_a[14]    19
set_io bus_a[15]    20
set_io bus_a[16]    21
set_io bus_a[17]    22
set_io bus_a[18]    23
set_io bus_a[19]    24
set_io bus_ior_l    25
set_io bus_iow_l    26
set_io bus_memr_l   28
set_io bus_memw_l   29
set_io bus_d[0]     31
set_io bus_d[1]     32
set_io bus_d[2]     33
set_io bus_d[3]     34
set_io bus_d[4]     37
set_io bus_d[5]     38
set_io bus_d[6]     39
set_io bus_d[7]     41
set_io bus_dir      42
set_io bus_rdy      43
set_io bus_0ws_l    44
set_io bus_aen      45
set_io bus_ale      47

### RAM
set_io ram_we_l     130
set_io ram_a[0]     105
set_io ram_a[1]     106
set_io ram_a[2]     110
set_io ram_a[3]     113
set_io ram_a[4]     115
set_io ram_a[5]     135
set_io ram_a[6]     137
set_io ram_a[7]     139
set_io ram_a[8]     142
set_io ram_a[9]     144
set_io ram_a[10]    143
set_io ram_a[11]    141
set_io ram_a[12]    138
set_io ram_a[13]    136
set_io ram_a[14]    134
set_io ram_a[15]    116
set_io ram_a[16]    114
set_io ram_a[17]    112
set_io ram_a[18]    107
set_io ram_d[0]     117
set_io ram_d[1]     119
set_io ram_d[2]     121
set_io ram_d[3]     124
set_io ram_d[4]     125
set_io ram_d[5]     122
set_io ram_d[6]     120
set_io ram_d[7]     118

### Video outputs
set_io hsync        60
set_io vsync        55
set_io d_r          61
set_io d_g          56
set_io d_b          48
set_io d_r2         73
set_io d_g2         74
set_io d_b2         62
set_io vid_en_l     75
set_io vga_hsync    102
set_io vga_vsync    104
set_io red[0]       93
set_io red[1]       94
set_io red[2]       95
set_io red[3]       96
set_io red[4]       97
set_io red[5]       98
set_io green[0]     83
set_io green[1]     84
set_io green[2]     85
set_io green[3]     87
set_io green[4]     88
set_io green[5]     90
set_io green[6]     91
set_io blue[0]      76
set_io blue[1]      78
set_io blue[2]      79
set_io blue[3]      80
set_io blue[4]      81
set_io blue[5]      82

# Config switch inputs
set_io switch2    101
set_io switch3    99

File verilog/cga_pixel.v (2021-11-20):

// Graphics Gremlin
//
// Copyright (c) 2021 Eric Schlaepfer
// This work is licensed under the Creative Commons Attribution-ShareAlike 4.0
// International License. To view a copy of this license, visit
// http://creativecommons.org/licenses/by-sa/4.0/ or send a letter to Creative
// Commons, PO Box 1866, Mountain View, CA 94042, USA.
//
`default_nettype none
module cga_pixel(
    input clk,
    input[4:0] clk_seq,
    input hres_mode,
    input grph_mode,
    input bw_mode,
    input mode_640,
    input tandy_16_mode,
    input thin_font,
    input[7:0] vram_data,
    input vram_read_char,
    input vram_read_att,
    input disp_pipeline,
    input charrom_read,
    input display_enable,
    input cursor,
    input[4:0] row_addr,
    input blink_enabled,
    input blink,
    input hsync,
    input vsync,
    input video_enabled,
    input[7:0] cga_color_reg,
    output[3:0] video
    );

    reg[7:0] attr_byte;
    reg[7:0] char_byte;
    reg[7:0] char_byte_old;
    reg[7:0] attr_byte_del;
    reg[7:0] charbits;
    reg[1:0] cursor_del;
    reg[1:0] display_enable_del;
    reg pix;
    reg pix_delay;
    reg[1:0] pix_bits;
    reg[1:0] pix_bits_old;
    reg[3:0] tandy_bits;
    wire pix_640;
    wire[10:0] rom_addr;
    wire load_shifter;
    wire[2:0] charpix_sel;

    // Character ROM
    reg[7:0] char_rom[0:4095];
    initial $readmemh("cga.hex", char_rom, 0, 4095);

    // Latch character and attribute data from VRAM
    // at appropriate times
    always @ (posedge clk)
    begin
        if (vram_read_char) begin
            char_byte <= vram_data;
            char_byte_old <= char_byte;
        end
        if (vram_read_att) begin
            attr_byte <= vram_data;
        end
    end

    // Fetch pixel data for graphics modes
    wire [2:0]muxin;
    assign muxin = hres_mode ? (clk_seq[3:1] + 3'd6) : (clk_seq[4:2] + 3'd7);
    always @ (*)
    begin
        if (video_enabled) begin
            // Hi-res vs low-res needs different adjustments
            // Normal CGA is low res only in graphics mode
            // Tandy uses "high res" mode for both 320x200x16
            // and 640x200x4 color modes
            case (muxin)
                3'd0: pix_bits <= char_byte[7:6];
                3'd1: pix_bits <= char_byte[5:4];
                3'd2: pix_bits <= char_byte[3:2];
                3'd3: pix_bits <= char_byte[1:0];
                3'd4: pix_bits <= attr_byte[7:6];
                3'd5: pix_bits <= attr_byte[5:4];
                3'd6: pix_bits <= attr_byte[3:2];
                3'd7: pix_bits <= attr_byte[1:0];
                default: pix_bits <= 2'b0;
            endcase
        end else begin
            pix_bits <= 2'b0;
        end
    end

    // Add a pipeline delay to the attribute byte data, cursor, and display
    // enable so they line up with the displayed character
    always @ (posedge clk)
    begin
        if (disp_pipeline) begin
            attr_byte_del <= video_enabled ? attr_byte : 8'd0;
            display_enable_del <= {display_enable_del[0], display_enable};
            cursor_del <= {cursor_del[0], cursor};
        end
    end

    // Look up character byte in our character ROM table
    assign rom_addr = {char_byte, row_addr[2:0]};
    always @ (posedge clk)
    begin
        // Only load character bits at this point
        if (charrom_read) begin
            charbits <= char_rom[{~thin_font, rom_addr}];
        end
    end

    // This must be a mux. Using a shift register causes very weird
    // issues with the character ROM and Yosys turns it into a bunch
    // of flip-flops instead of a ROM.
    assign charpix_sel = hres_mode ? (clk_seq[3:1] + 3'd6) : (clk_seq[4:2] + 3'd7);
    always @ (*)
    begin
        if (video_enabled) begin
            // Hi-res vs low-res needs different adjustments
            case (charpix_sel)
                5'd0: pix <= charbits[7];
                5'd1: pix <= charbits[6];
                5'd2: pix <= charbits[5];
                5'd3: pix <= charbits[4];
                5'd4: pix <= charbits[3];
                5'd5: pix <= charbits[2];
                5'd6: pix <= charbits[1];
                5'd7: pix <= charbits[0];
                default: pix <= 0;
            endcase
        end else begin
            pix <= 0;
        end
    end

    // In 640x200 mode, alternate between the two bits from
    // the shift register outputs at specific times in the sequence
    wire[2:0] tmp_clk_seq;
    assign tmp_clk_seq = clk_seq + 3'd7;
    assign pix_640 = tmp_clk_seq[1] ? pix_bits[0] : pix_bits[1];

    // In Tandy 320x200x16 mode, concatenate two adjacent pixels
    wire temp;
    assign temp = clk_seq[1:0] == 2'b00;
    always @ (posedge clk)
    begin
        if (clk_seq[0]) begin
            if (clk_seq[1]) begin
                tandy_bits <= {pix_bits_old, pix_bits};
            end else begin
                pix_bits_old <= pix_bits;
            end
        end
    end

    // Add one clk cycle delay to match up pixel data with attribute byte
    // data.
    always @ (posedge clk)
    begin
        pix_delay <= pix;
    end

    // Applies video attributes, generates final video
    cga_attrib attrib (
        .clk(clk),
        .att_byte(attr_byte_del),
        .row_addr(row_addr),
        .cga_color_reg(cga_color_reg),
        .grph_mode(grph_mode),
        .bw_mode(bw_mode),
        .mode_640(mode_640),
        .tandy_16_mode(tandy_16_mode),
        .display_enable(display_enable_del[0]),
        .blink_enabled(blink_enabled),
        .blink(blink),
        .cursor(cursor_del[0]),
        .hsync(hsync),
        .vsync(vsync),
        .pix_in(pix_delay),
        .c0(pix_bits[0]),
        .c1(pix_bits[1]),
        .pix_640(pix_640),
        .pix_tandy(tandy_bits),
        .pix_out(video)
    );

endmodule

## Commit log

2021-05-14 pcb files
    [RAM.sch, bus_interface.sch, isavideo.csv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]
2021-05-16 Fix BOM swap of 1u and 4.7u caps
    [RAM.sch, bus_interface.sch, isavideo.csv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]
2021-05-16 corrected board dimensions
    [isavideo.kicad_pcb]
2021-06-06 Fix SRAM manufacturer part number
    [RAM.sch, isavideo.csv]
2021-06-12 Added bracket dimensions
    [isavideo.kicad_pcb]
2021-07-08 Disable CGA snow. Fix artifact colors. Add partial Tandy support.
    [cga_pixel.v, cga_vram.v]
2021-09-04 Add 3d-printable bracket
    [isabracket.stl]
2021-11-20 Fix CGA text mode pixel mux bug
    [cga_pixel.v]

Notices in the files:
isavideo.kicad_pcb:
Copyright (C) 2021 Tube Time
